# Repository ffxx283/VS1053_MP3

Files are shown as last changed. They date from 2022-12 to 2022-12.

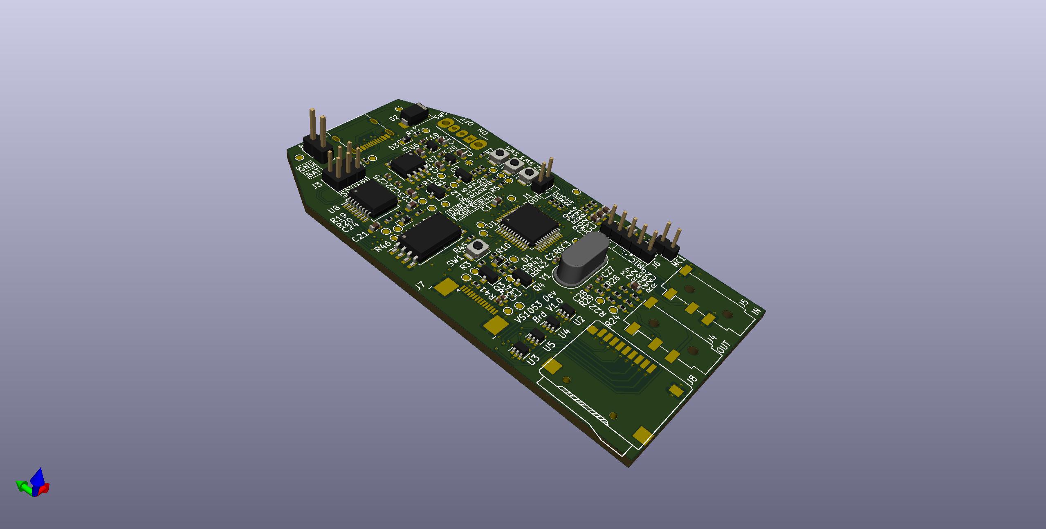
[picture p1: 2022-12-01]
Hardware_Project/效果图/正面.jpg

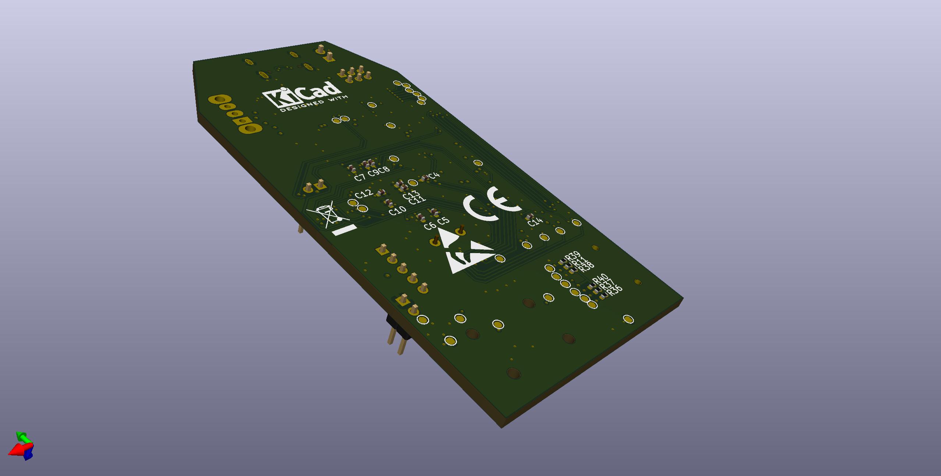
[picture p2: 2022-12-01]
Hardware_Project/效果图/反面.jpg

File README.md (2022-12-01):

# VS1053_MP3
基于VS1053芯片设计的MP3播放器

产品定位为一款可以对VS1053进行全面开发的开发板，产品的功能应当全面覆盖芯片的所有外设资源，但应该以将VS1053作为主控为重点，适当开发从机功能（SPI控制）。
TYPE-C接口，插入电脑直接对开发板进行下载调试（板载下载器），将读写SD卡的功能也加入此接口中（读卡器功能），可以使用跳线帽进行选择USB的通路。
带有液晶显示屏或者是OLED显示屏，带有按键，方便进行交互。

TYPE-C接口，插入电脑直接对开发板进行下载调试（板载下载器），将读写SD卡的功能也加入此接口中（读卡器功能），可以使用跳线帽进行选择USB的通路。

带有液晶显示屏或者是OLED显示屏，带有按键，方便进行交互。

主控：VS1053
USB转串口芯片：CH340N
SPI存储器芯片：AT93C66
电源芯片：RT9193-33GB、RT9193-18GB
SD卡控制器芯片：GL823
模拟单刀双掷开关SGM3157YC6/TR
显示屏选型：鸿欣达----YT144S025不带触摸
存储设备：TF卡
音频输入输出：3.5mm耳机孔输出+板载MIC

……
不测试了，下载调试软件的时候，软件直接就崩溃了，多次测试均未见效果，当成一个读卡器来用吧
VS1053芯片的生态不行，目前市面上大部分都是把它当做一个从机芯片来用，用作主机的案例太少，
官方对于此方面不够重视，软件也存在各种各样的问题，折腾不下去了。

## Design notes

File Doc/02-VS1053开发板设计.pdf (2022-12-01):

# VS1053开发板设计文档

冯星

1、设计需求

1.1、功能要求

1.2、芯片选型

2、电路设计

2.1、电源设计

2.1.1、供电

2.2、Type-C接口设计

2.2.1、串口下载和读写TF卡

2.2.2、VS1053和GL823对TF卡读取冲突

2.3、VS1053芯片电路设计

2.3.1、芯片电源、时钟、复位

2.3.2、芯片配置

2.3.3、程序存储

2.4、TF卡电路设计

2.5、音频电路设计

2.6、其他电路设计

2.6.1、显示屏接口

2.6.2、按键、LED电路

2.6.3、状态指示电路

### 1、设计需求

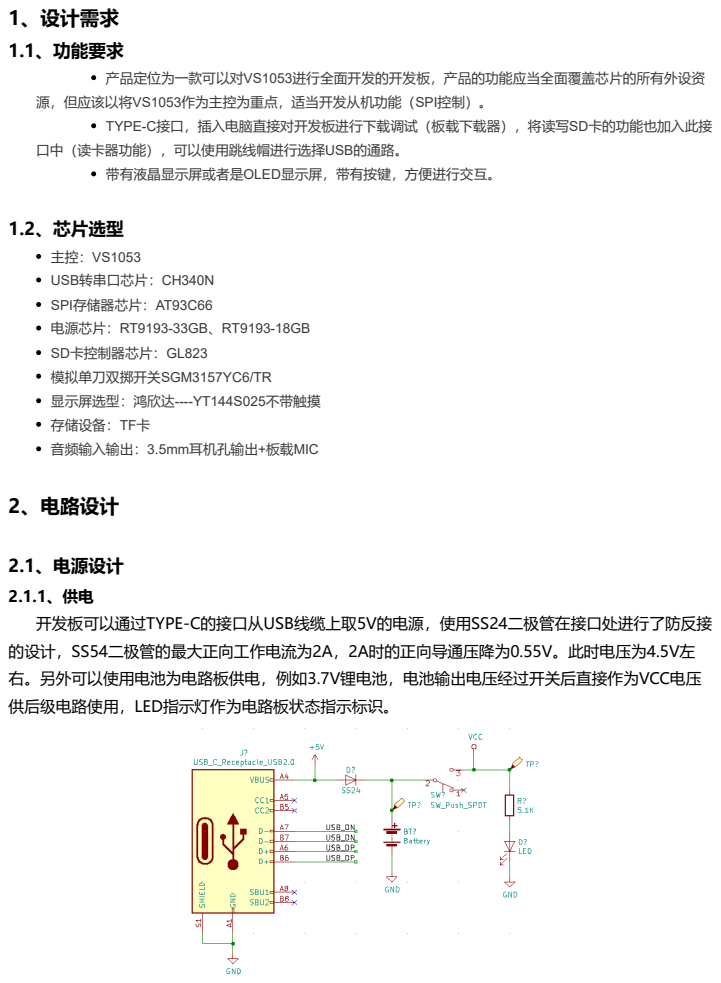
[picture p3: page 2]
1.1、功能要求; 产品定位为一款可以对VS1053进行全面开发的开发板，产品的功能应当全面覆盖芯片的所有外设资 源，但应该以将VS1053作为主控为重点，适当开发从机功能（SPI控制）。; 1.2、芯片选型; USB转串口芯片：CH340N; SPI存储器芯片：AT93C66; 电源芯片：RT9193-33GB、RT9193-18GB; SD卡控制器芯片：GL823; 模拟单刀双掷开关SGM3157YC6/TR 显示屏选型：鸿欣达----YT144S025不带触摸 存储设备：TF卡 音频输入输出：3.5mm耳机孔输出+板载MIC; 2、电路设计; 2.1、电源设计; 2.1.1、供电 开发板可以通过TYPE-C的接口从USB线缆上取5V的电源，使用SS24二极管在接口处进行了防反接 的设计，SS54二极管的最大正向工作电流为2A，2A时的正向导通压降为0.55V。此时电压为4.5V左 右。另外可以使用电池为电路板供电，例如3.7V锂电池，电池输出电压经过开关后直接作为VCC电压 供后级电路使用，LED指示灯作为电路板状态指示标识。

TYPE-C接口，插入电脑直接对开发板进行下载调试（板载下载器），将读写SD卡的功能也加入此接

口中（读卡器功能），可以使用跳线帽进行选择USB的通路。

带有液晶显示屏或者是OLED显示屏，带有按键，方便进行交互。

电路板的一级电源使用RT9193系列LDO电源芯片获得3.3V和1.8V的电压，芯片的输入电压范围为 2.5V~5.5V,最大输入电压不得超过6V，输出电压的精度为±2%，典型输出电流为400mA，关断电流 为0.01uA。使用3.3V型号1.8V的芯片型号为VS1053和其他外设供电，输入输出电容均采用手册推荐 的值。

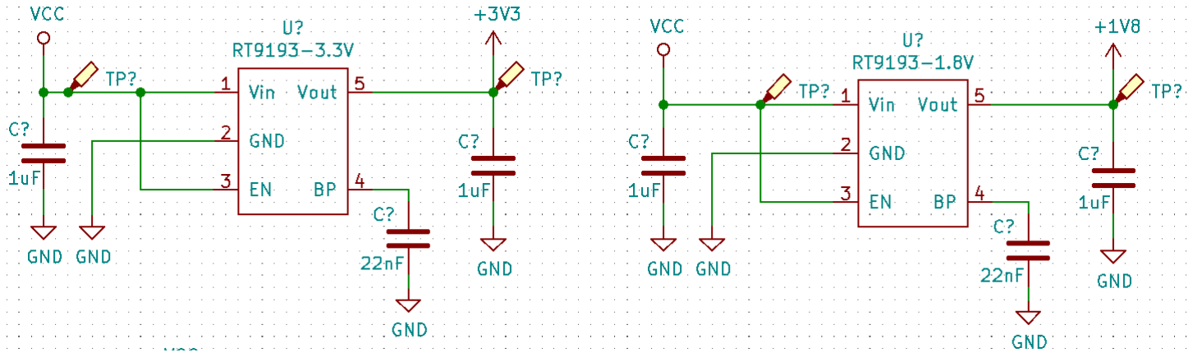
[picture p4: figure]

2.2、Type-C接口设计
2.2.1、串口下载和读写TF卡
USB线插入后给设备供电，系统开始工作，Type-C接口支持正反插。

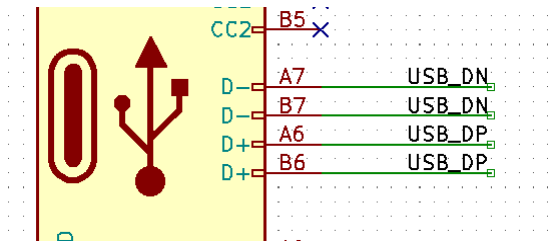
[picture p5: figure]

串口下载程序的功能和读写TF卡的功能可以使用跳冒手动设置，设置USB_DP和DN连接到不同的 USB网络上即可。

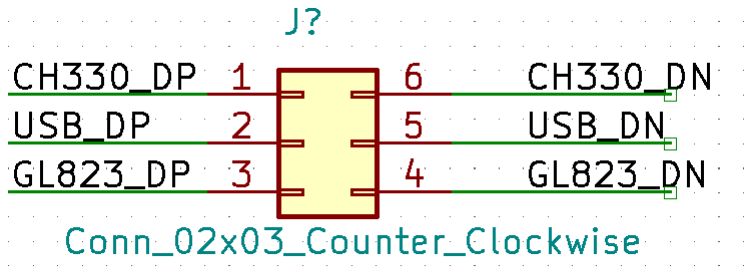
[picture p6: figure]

串口下载程序大部分使用于调试开发阶段，用于给VS1053芯片烧录程序，使用CH330N型号的 USB转串口芯片，此芯片不需要设置外部晶振即可工作。

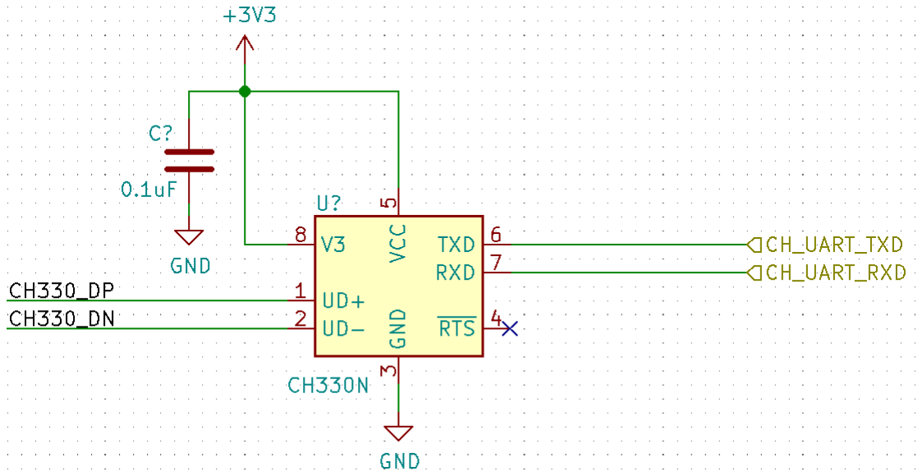
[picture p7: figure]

读写TF卡功能用于从电脑上往TF卡中存储数据，这样就不需要将TF取出，插入读卡器中再进行歌 曲的更新了，直接使用Type-C接口即可进行读写，大大简化了操作步骤。 芯片的供电电压为5V，只有在USB设备插入的时候才会有5V的电压，而且必须软件控制设备打卡 5V的电源控制开关，这样才可成功得给GL823K芯片供电。

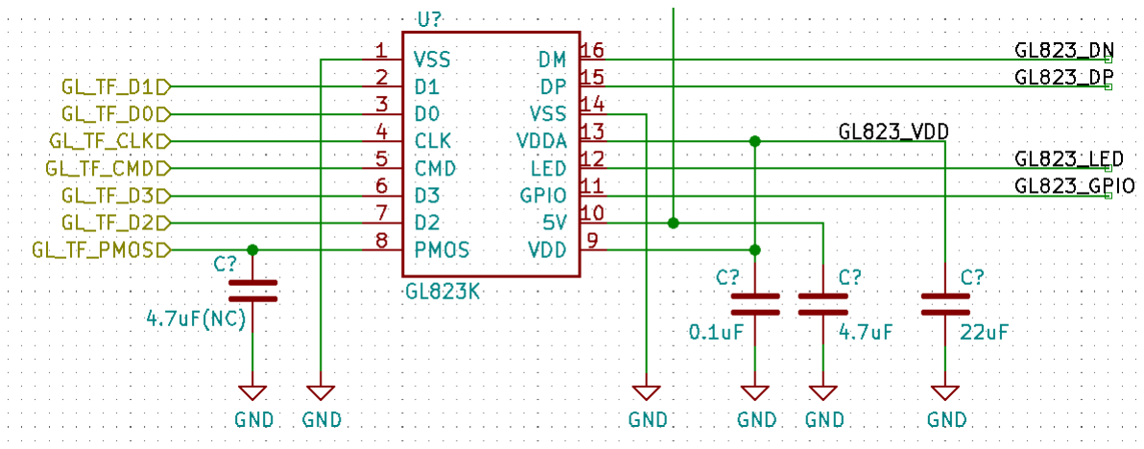
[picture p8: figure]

2.2.2、VS1053和GL823对TF卡读取冲突 GL823芯片和VS1053都需要对TF卡进行读写，如何设置GL823与VS1053两个芯片自动切换对TF 卡的使用权。
官方的开发板的解决方案是：检测是否有USB设备插入，来设置三态门芯片，间接控制TF卡被不同 的主控芯片所控制。但是官方的板子带有电池，在不插入TF卡的时候是可以使用电池供电来使得 VS1053控制TF卡的，插入USB后，VS1053不播放音乐，从而设置三态门的开关，使得TF读卡芯片 （CBM4082）对TF卡进行读写。而且官方板上的CBM4082读卡器芯片是带有使能端的，USB的供电 电源提供这个使能信号。
本开发板使用的方案：使用模拟单刀双掷开关SGM3157YC6/TR来进行TF卡信号的切换，将芯片 的公共端连接在TF卡的控制信号上，将常闭端连接到VS1053的TF卡控制信号线上，常开端连接在 GL823的TF卡控制信号线上；

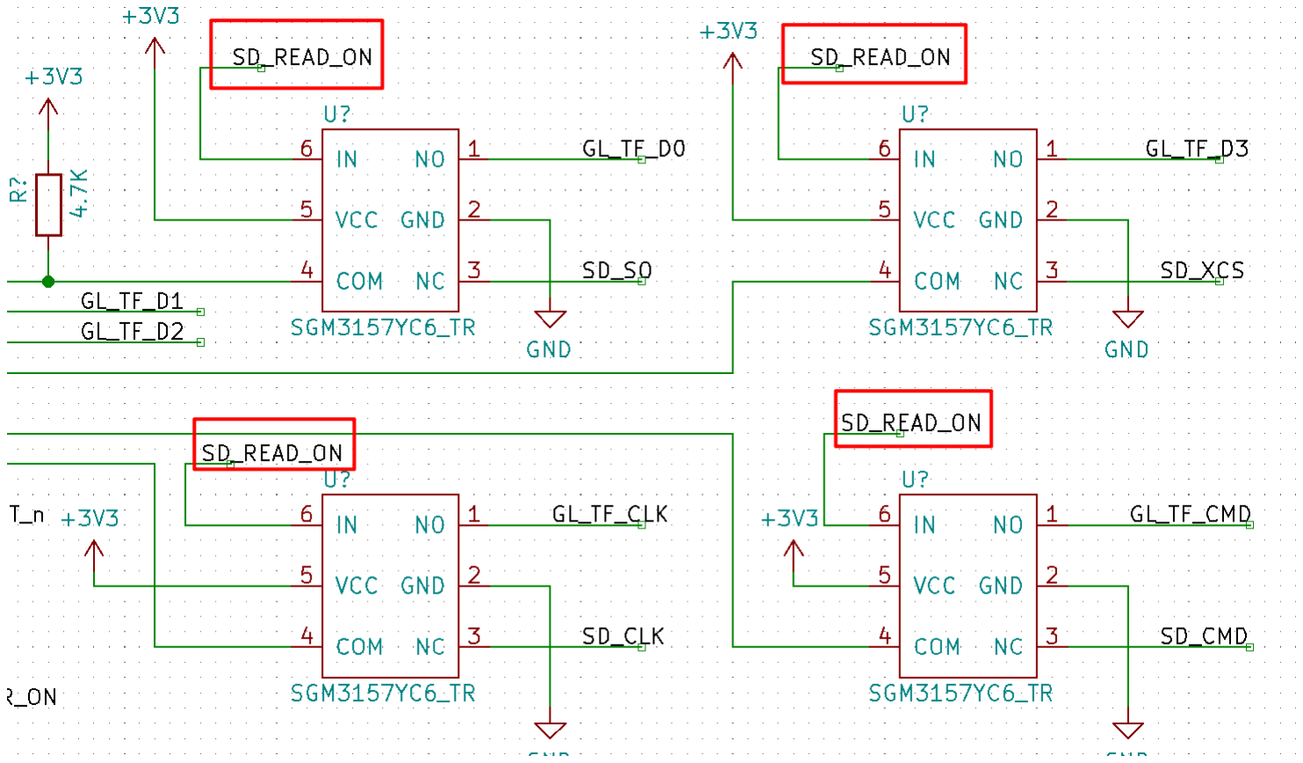
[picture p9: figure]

模拟开关的控制信号连接到VS1053的一个IO（默认为低电平），系统上电（USB供电或者电池供 电）默认状态下开发板上的VS1053读取TF卡播放音频，当需要对TF卡进行读写操作时，VS1053控制 IO口输出高电平，GL823芯片通电，然后读写TF卡。

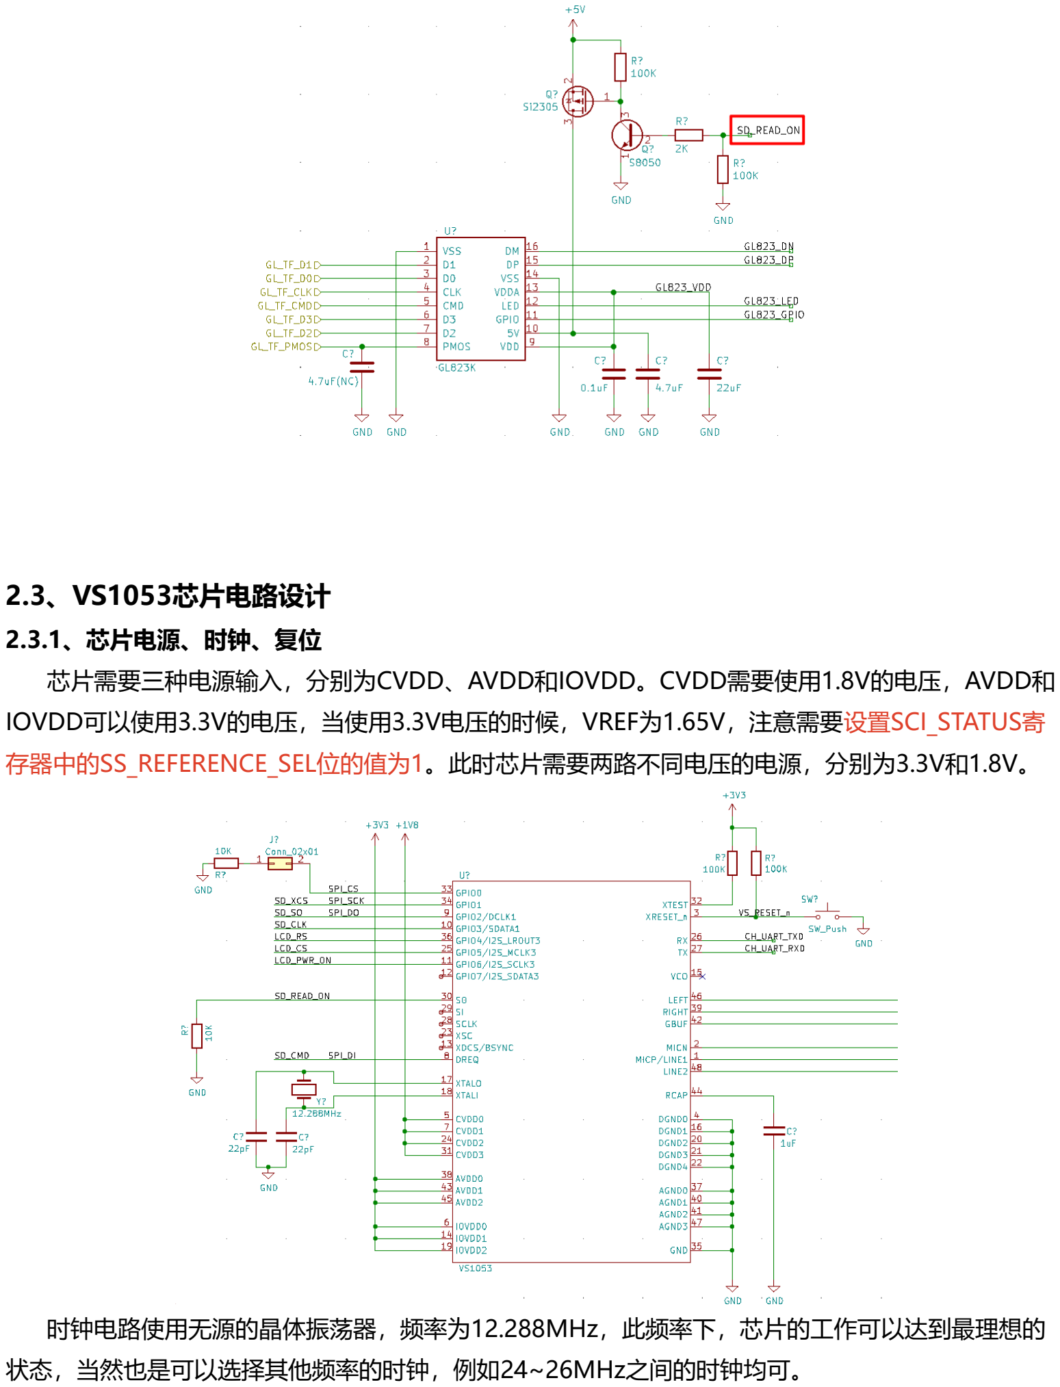
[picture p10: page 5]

2.3、VS1053芯片电路设计
2.3.1、芯片电源、时钟、复位
芯片需要三种电源输入，分别为CVDD、AVDD和IOVDD。CVDD需要使用1.8V的电压，AVDD和 IOVDD可以使用3.3V的电压，当使用3.3V电压的时候，VREF为1.65V，注意需要设置SCI_STATUS寄 存器中的SS_REFERENCE_SEL位的值为1。此时芯片需要两路不同电压的电源，分别为3.3V和1.8V。

时钟电路使用无源的晶体振荡器，频率为12.288MHz，此频率下，芯片的工作可以达到最理想的 状态，当然也是可以选择其他频率的时钟，例如24~26MHz之间的时钟均可。

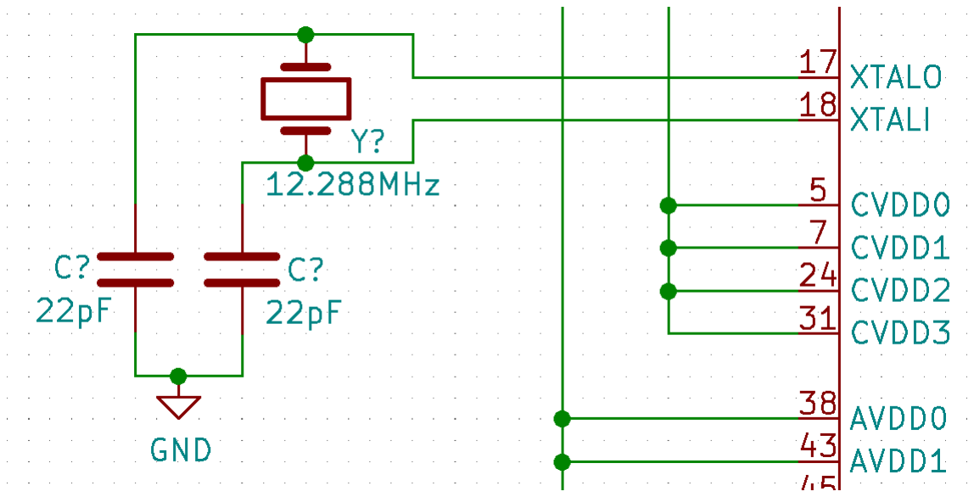
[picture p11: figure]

复位电路，低电平有效。外部上拉至3.3V，需要复位的时候，使用外部按键将其下拉到GND，IO 处于低电平，完成复位操作。

2.3.2、芯片配置

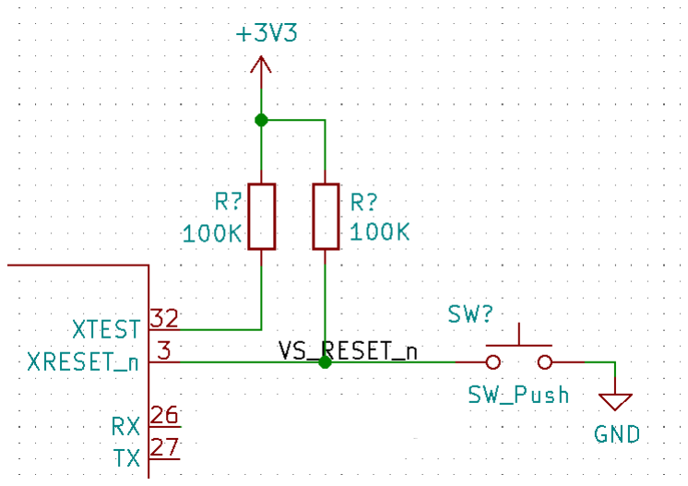
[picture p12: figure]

XTEST引脚为芯片保留引脚，根据芯片手册要求，上拉到IOVDD电源上，即3.3V电源。

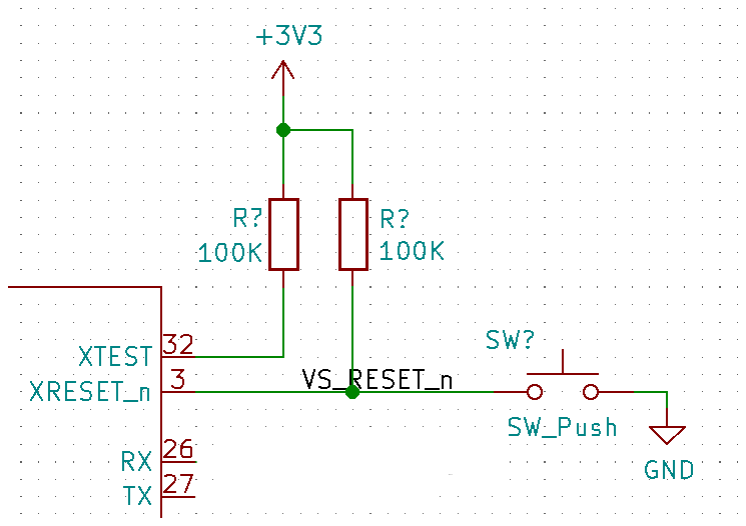
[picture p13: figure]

RCAP引脚使用一个1uF的电容连接到GND网络。

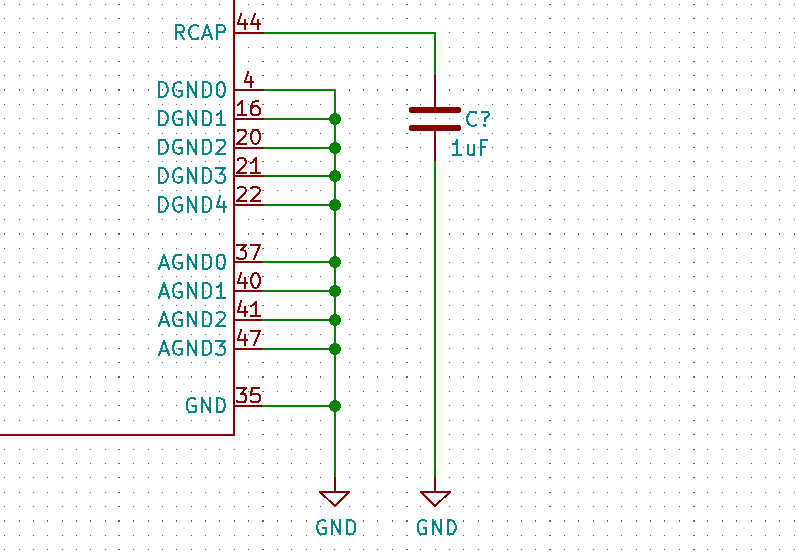
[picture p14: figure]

当芯片启动时，GPIO0引脚为高电平，则芯片就有进入SPI BOOT模式，即从SPI存储器件中读取程 序代码来运行，如下图使用100KOhm的电阻上拉引脚到3.3V，同时准备了一个跳线帽用来设置其接 地。

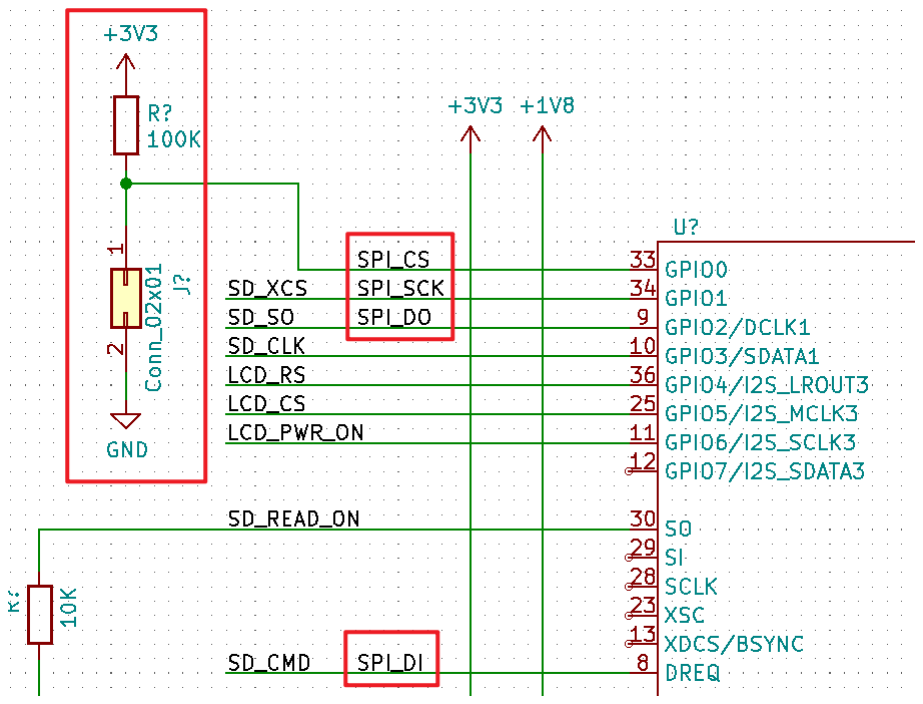
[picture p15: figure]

当进入SPI BOOT模式的时候，芯片的几个多功能引脚功能会发生相应的变化，如下表所示的为此 时芯片引脚的功能。

2.3.3、程序存储

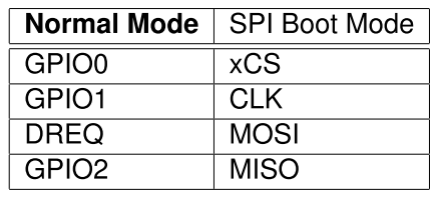
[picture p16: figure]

VS1053芯片的数据手册要求“The memory has to be an SPI Bus Serial EEPROM with 16-bit or 24-bit addresses. ”。由于SPI接口的FLASH芯片较多，但是SPI接口的EEPROM不常见，所以使 用两个芯片进行设计，最终选择哪个需要设计验证。
AT93C66芯片是Atmel公司的4Kbits的三线串行EEPROM存储器，由于要求16bits的Address， AT93C66手册的要求“When the ORG pin is connected to VCC, the x 16 organization is selected. When it is connected to ground, the x 8 organization is selected.”，设置ORG的引脚 可以连接到VCC电压上，也可以连接到GND上，默认设置到GND上，使用8bits数据位宽。 W25Q32是Winbond的32Mbits SPI FLASH芯片，具有24bits的地址线位宽，虽然VS1053手册 中写到的是SPI EEPROM，但是官方开发板上使用的就是W25X16或者GD25Q16系列的FLASH芯片， 使用此芯片做测试。

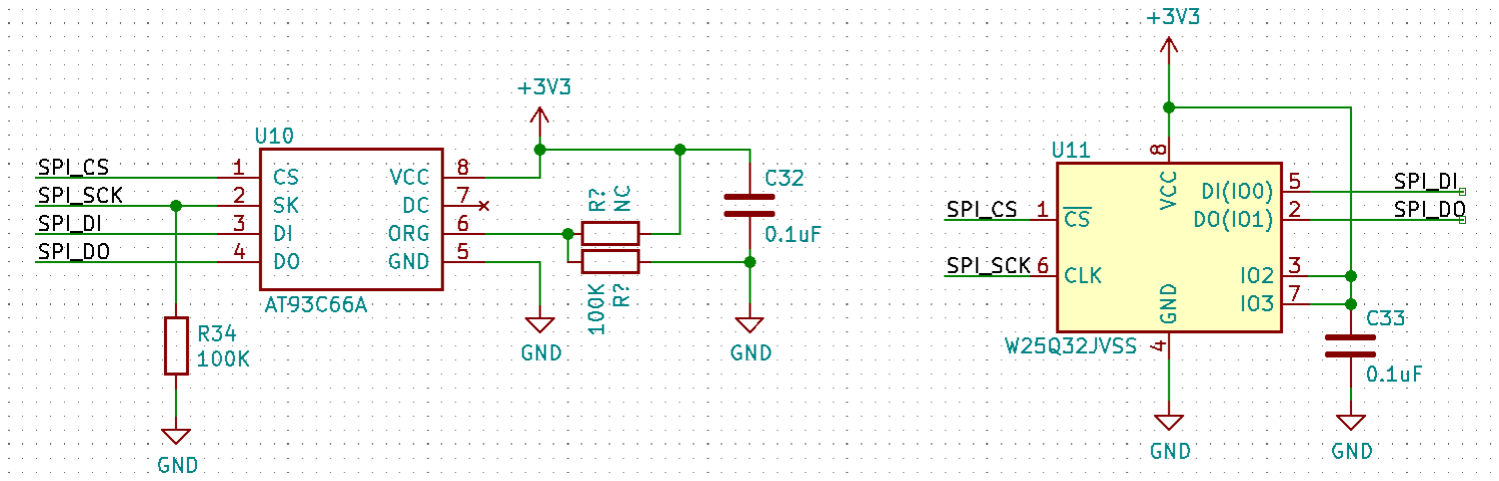
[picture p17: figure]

2.4、TF卡电路设计

参考官方的开发板设计TF卡电路如下图，VS1053是使用的SPI或者单线SDIO来读取的TF卡中数 据，而读卡器芯片GL823是使用的四线的SDIO来读取TF卡中的内容。

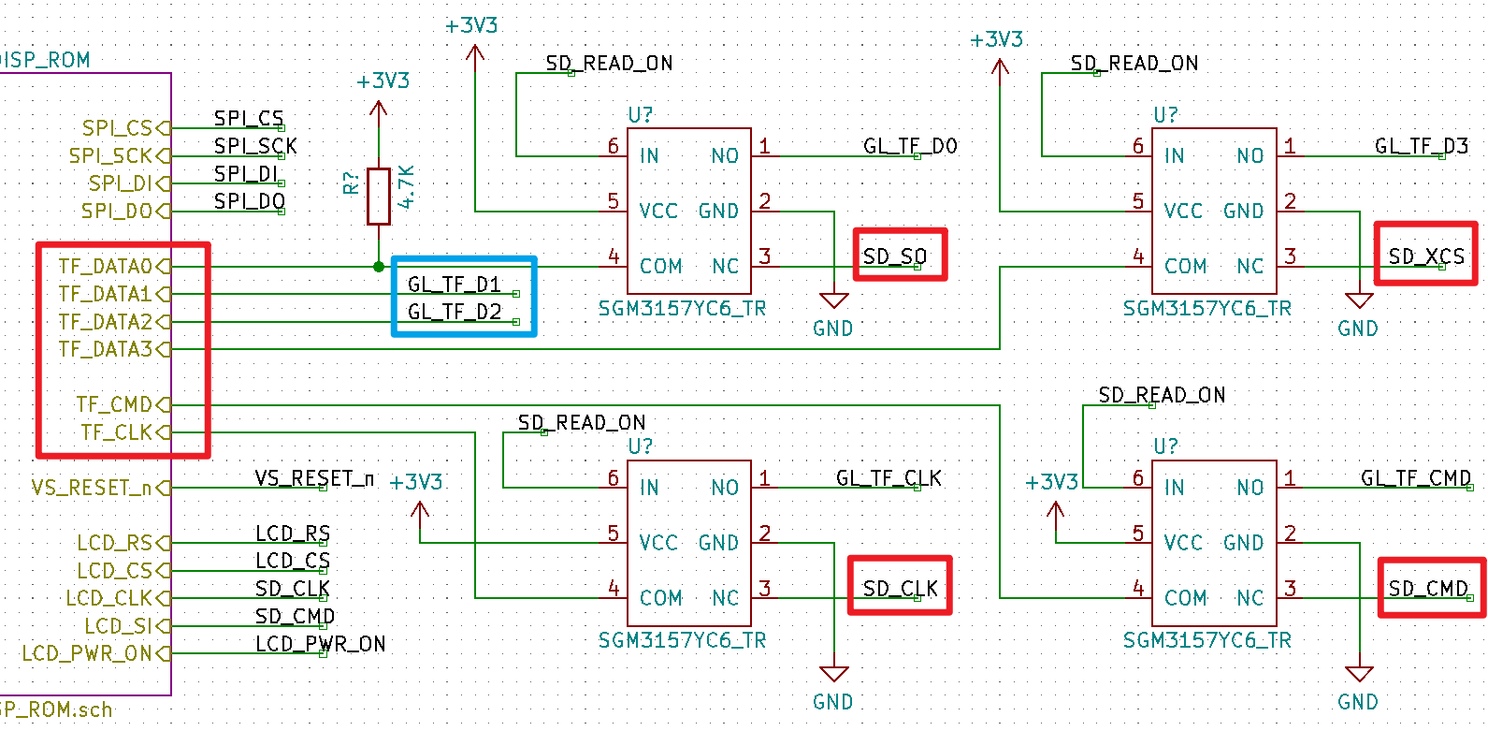
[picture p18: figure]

2.5、音频电路设计
参考官方电路设计：

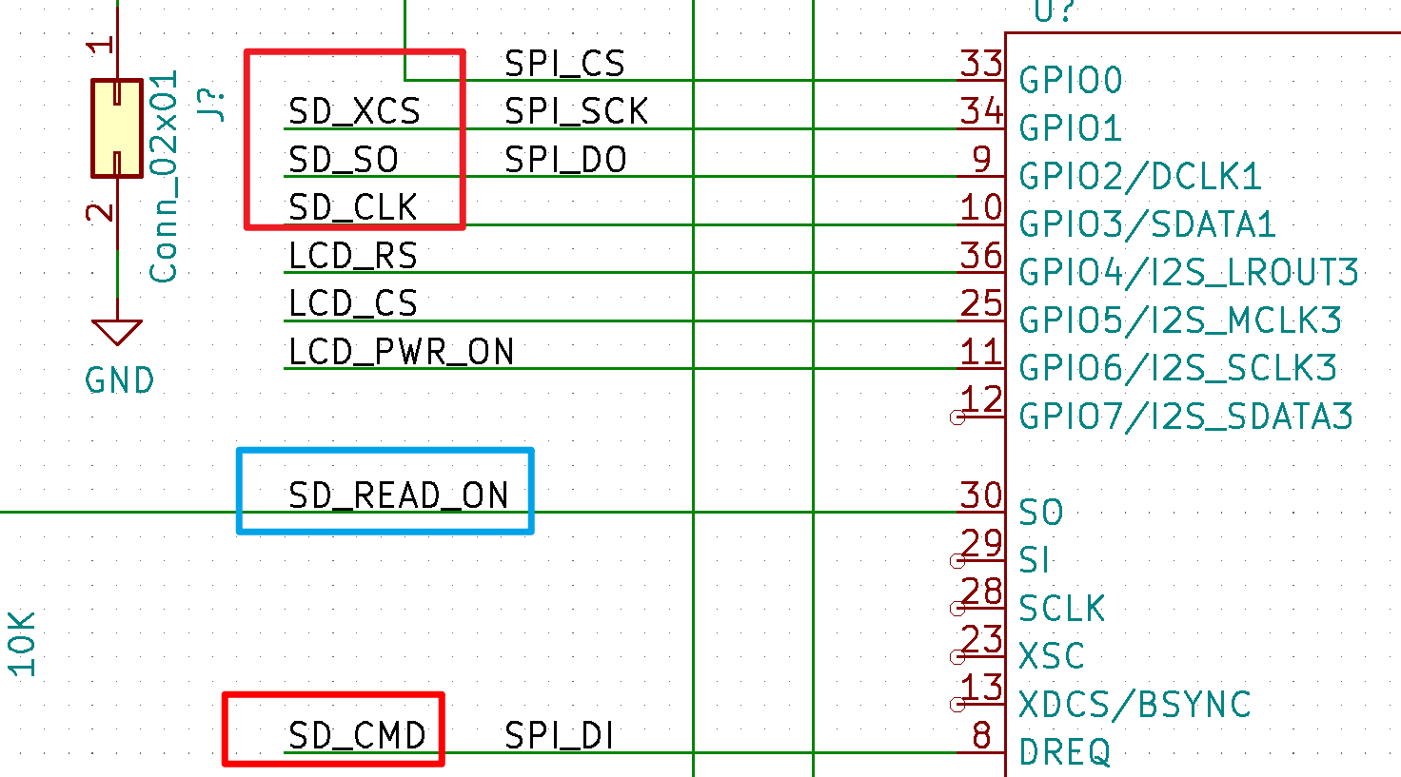
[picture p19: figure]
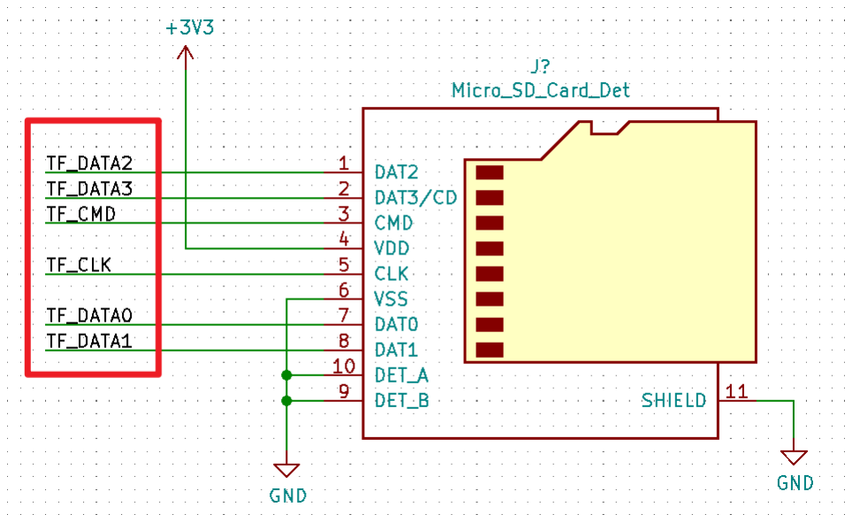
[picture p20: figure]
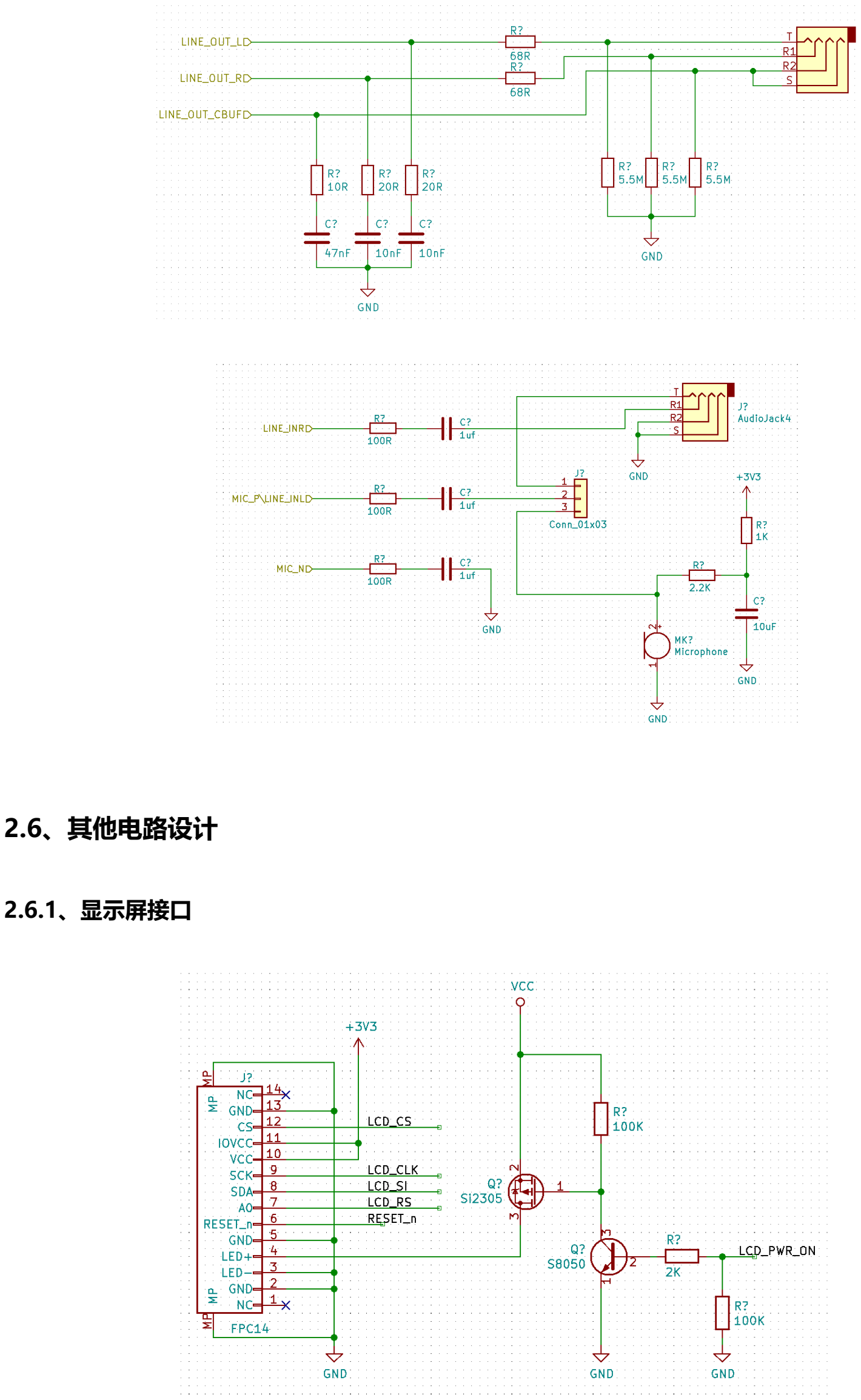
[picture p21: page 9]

2.6、其他电路设计

2.6.1、显示屏接口

2.6.2、按键、LED电路
参考官方开发板的按键IO分配策略，

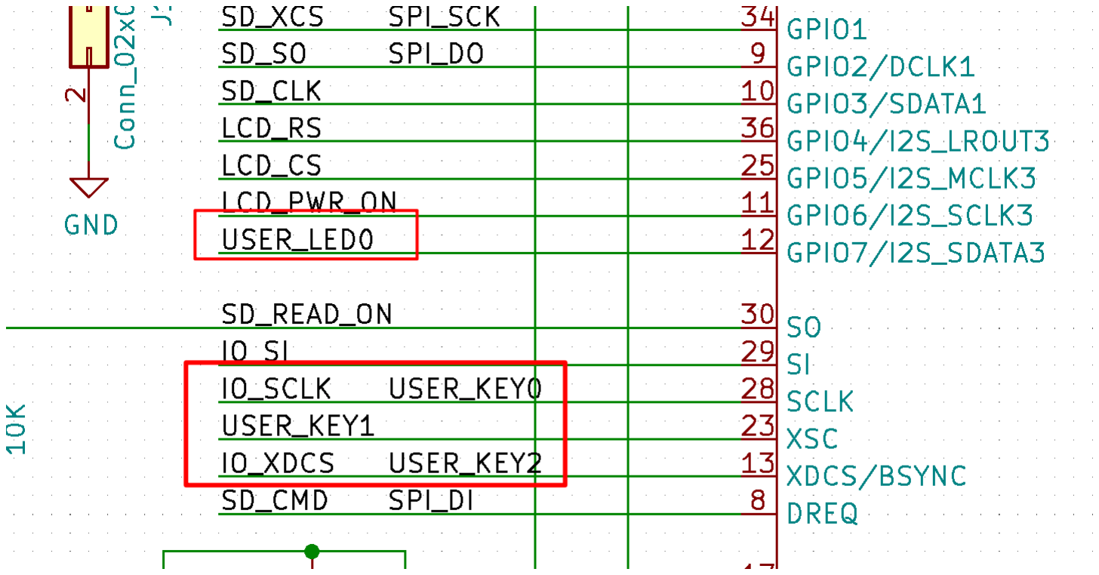
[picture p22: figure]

2.6.3、状态指示电路

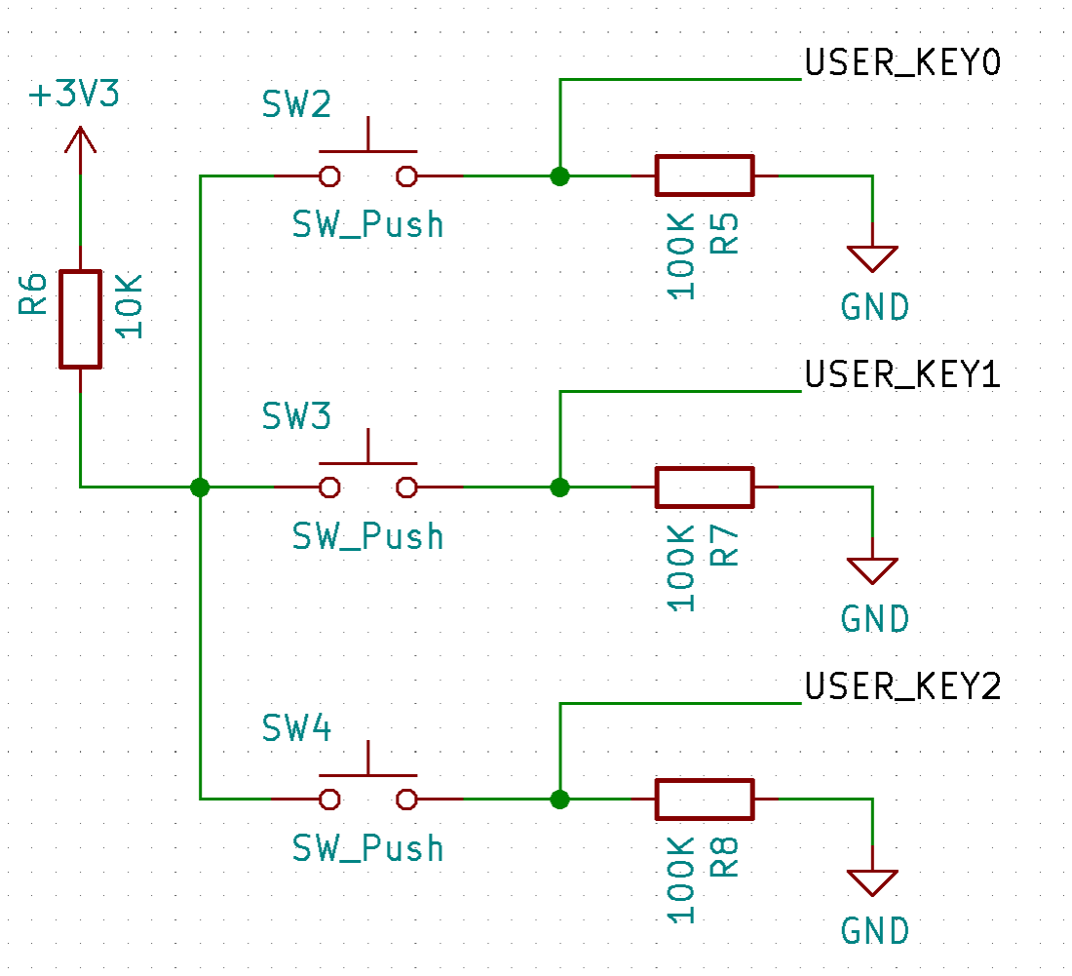
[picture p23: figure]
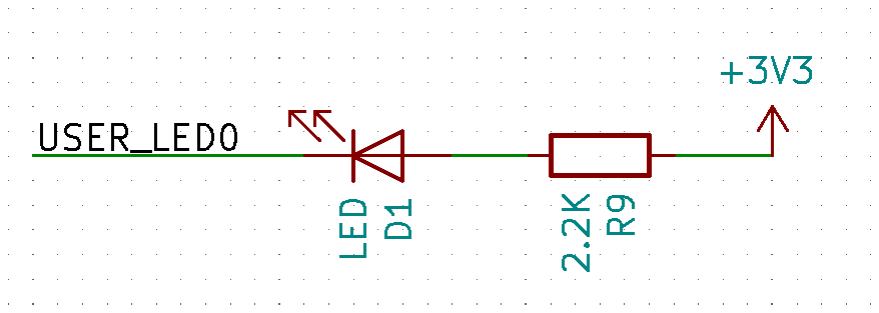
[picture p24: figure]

使用一颗LED灯来指示GL823的工作状态。

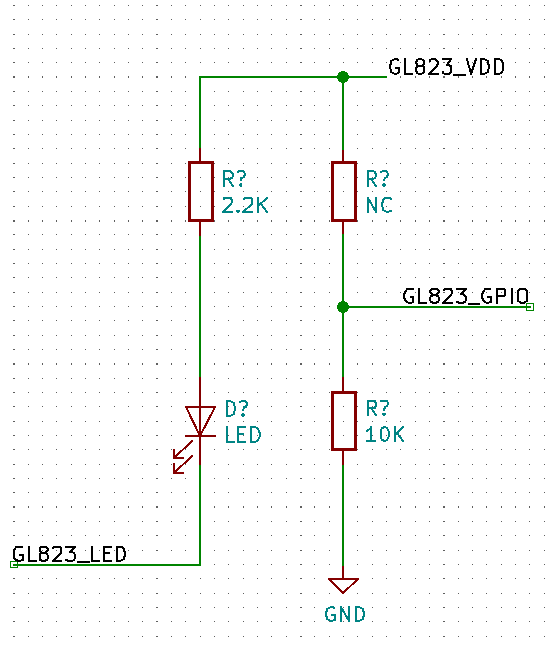
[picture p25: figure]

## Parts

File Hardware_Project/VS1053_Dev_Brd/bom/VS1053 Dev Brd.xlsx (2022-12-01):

Item | Qty | Reference(s) | Value | Footprint | 采购情况 | 总价(元)
1 | 1 | BT1 | Battery | Connector_PinHeader_2.54mm:PinHeader_1x02_P2.54mm_Vertical | /
2 | 8 | C1, C15, C16, C17, C18, C29, C30, C32 | 1uF | Capacitor_SMD:C_0603_1608Metric | 50 | 2
3 | 2 | C2, C3 | 22pF | Capacitor_SMD:C_0402_1005Metric | 100 | 1.5
 | 17 | C4, C5, C6, C7, C8, C9, C10, C11, C12, C13, C14, C22, C25, C33, C34, C35, C36 | 0.1uF | Capacitor_SMD:C_0402_1005Metric | 100 | 1.5
 | 2 | C19, C20 | 22nF | Capacitor_SMD:C_0402_1005Metric | 100 | 1.5
 | 1 | C21 | 4.7uF(NC) | Capacitor_SMD:C_0603_1608Metric | /
 | 1 | C23 | 4.7uF | Capacitor_SMD:C_0603_1608Metric | 50 | 2.5
 | 2 | C24, C31 | 10uF | Capacitor_SMD:C_0603_1608Metric | 50 | 3
 | 1 | C26 | 47nF | Capacitor_SMD:C_0603_1608Metric | 50 | 2
 | 2 | C27, C28 | 10nF | Capacitor_SMD:C_0402_1005Metric | 100 | 1.5
 | 3 | D1, D3, D4 | LED | Diode_SMD:D_0603_1608Metric | 100 | 1
 | 1 | D2 | SS24 | Diode_SMD:D_SMA | 10 | 0.3
 | 1 | J1 | Conn_02x01 | Connector_PinHeader_2.00mm:PinHeader_1x02_P2.00mm_Vertical | 1 | 0.14
 | 1 | J2 | USB_C_Receptacle_USB2.0 | Connector_USB:USB_C_Receptacle_Palconn_UTC16-G | /
 | 1 | J3 | Conn_02x03_Counter_Clockwise | Connector_PinHeader_2.00mm:PinHeader_2x03_P2.00mm_Vertical | 1 | 0.28
 | 2 | J4, J5 | AudioJack4 | Connector_Audio:Jack_3.5mm_PJ320D_Horizontal | 3 | 0.36
 | 1 | J6 | Conn_01x05 | Connector_PinHeader_2.00mm:PinHeader_1x05_P2.00mm_Vertical | /
 | 1 | J7 | FPC14 | Connector_FFC-FPC:TE_1-1734839-4_1x14-1MP_P0.5mm_Horizontal | 1 | 8 | TFT显示屏
 | 1 | J8 | Micro_SD_Card_Det | Connector_Card:SD-MINI-X | 2 | 0.32
 | 1 | MC1 | Microphone | Connector_PinHeader_2.00mm:PinHeader_1x02_P2.00mm_Vertical | 1 | 0.3
 | 2 | Q1, Q3 | Si2305 | Package_TO_SOT_SMD:SOT-23 | 3 | 0.34
 | 2 | Q2, Q4 | S8050 | Package_TO_SOT_SMD:SOT-23 | 100 | 2
 | 11 | R1, R2, R3, R5, R8, R9, R12, R17, R35, R43, R46 | 100K | Resistor_SMD:R_0402_1005Metric | 100 | 1.8
 | 6 | R4, R7, R11, R13, R20, R45 | 10K | Resistor_SMD:R_0402_1005Metric | 100 | 1.8
 | 1 | R6 | NC(5.6M) | Resistor_SMD:R_0402_1005Metric | /
 | 5 | R10, R16, R18, R33, R42 | 2.2K | Resistor_SMD:R_0402_1005Metric | 100 | 1.8
 | 3 | R14, R15, R41 | NC(0R) | Resistor_SMD:R_0402_1005Metric | 100 | 1.8
 | 8 | R19, R21, R36, R37, R38, R39, R40, R44 | NC(10K) | Resistor_SMD:R_0402_1005Metric | /
 | 2 | R22, R23 | 68R/100R | Resistor_SMD:R_0402_1005Metric | /
 | 3 | R24, R25, R26 | 5.6M | Resistor_SMD:R_0402_1005Metric | 100 | 1.8
 | 3 | R27, R28, R29 | 20R | Resistor_SMD:R_0402_1005Metric | 100 | 1.8
 | 3 | R30, R31, R34 | 100R | Resistor_SMD:R_0402_1005Metric | 100 | 1.8
 | 1 | R32 | 1K | Resistor_SMD:R_0402_1005Metric | 100 | 1.8
 | 4 | SW1, SW2, SW3, SW4 | SW_Push | Button_Switch_SMD:SW_SPST_B3U-1000P | 10 | 0.9
 | 1 | SW5 | SW_Push_SPDT | Button_Switch_THT:SW_CuK_OS102011MA1QN1_SPDT_Angled | 20 | 1.5
 | 1 | U1 | VS1053 | Package_QFP:LQFP-48_7x7mm_P0.5mm | 1 | 16
 | 4 | U2, U3, U4, U5 | SGM3157YC6_TR | Package_TO_SOT_SMD:SOT-363_SC-70-6 | 5 | 1.2
 | 1 | U6 | RT9193-3.3V | Package_TO_SOT_SMD:SOT-353_SC-70-5 | 1 | 0.42 | RT9013
 | 1 | U7 | RT9193-1.8V | Package_TO_SOT_SMD:SOT-353_SC-70-5 | 1 | 0.24
 | 1 | U8 | GL823K | Package_SO:SSOP-16_5.3x6.2mm_P0.65mm | 1 | 2
 | 1 | U9 | CH330N | Package_SO:SOIC-8_3.9x4.9mm_P1.27mm | 1 | 1.78
 | 1 | U10 | AT93C66A | Package_SO:SOIC-8_5.275x5.275mm_P1.27mm | 1 | 0.59
 | 1 | U11 | W25Q32JVSS | Package_SO:SOIC-8_5.275x5.275mm_P1.27mm | /
 | 1 | Y1 | 12.288MHz | Crystal:Crystal_HC49-4H_Vertical | 1 | 0.19
 |  |  |  | 2mm跳线帽 | 100 | 3

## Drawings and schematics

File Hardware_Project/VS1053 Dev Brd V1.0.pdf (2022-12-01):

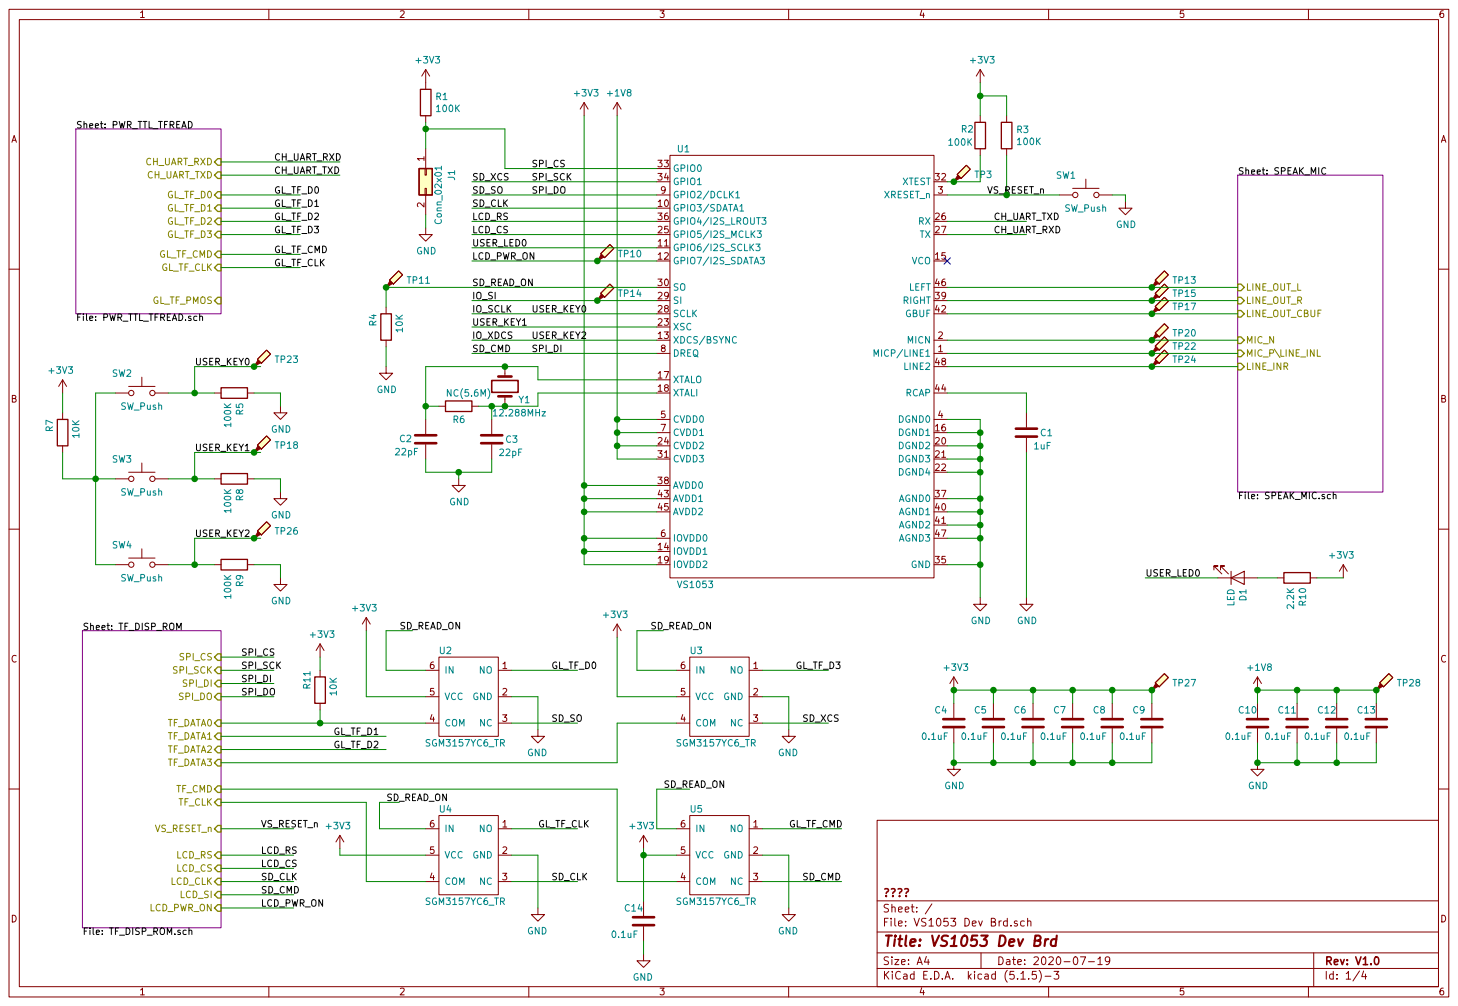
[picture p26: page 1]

File: VS1053 Dev Brd.sch Sheet: /
Id: 1/4 Title: VS1053 Dev Brd

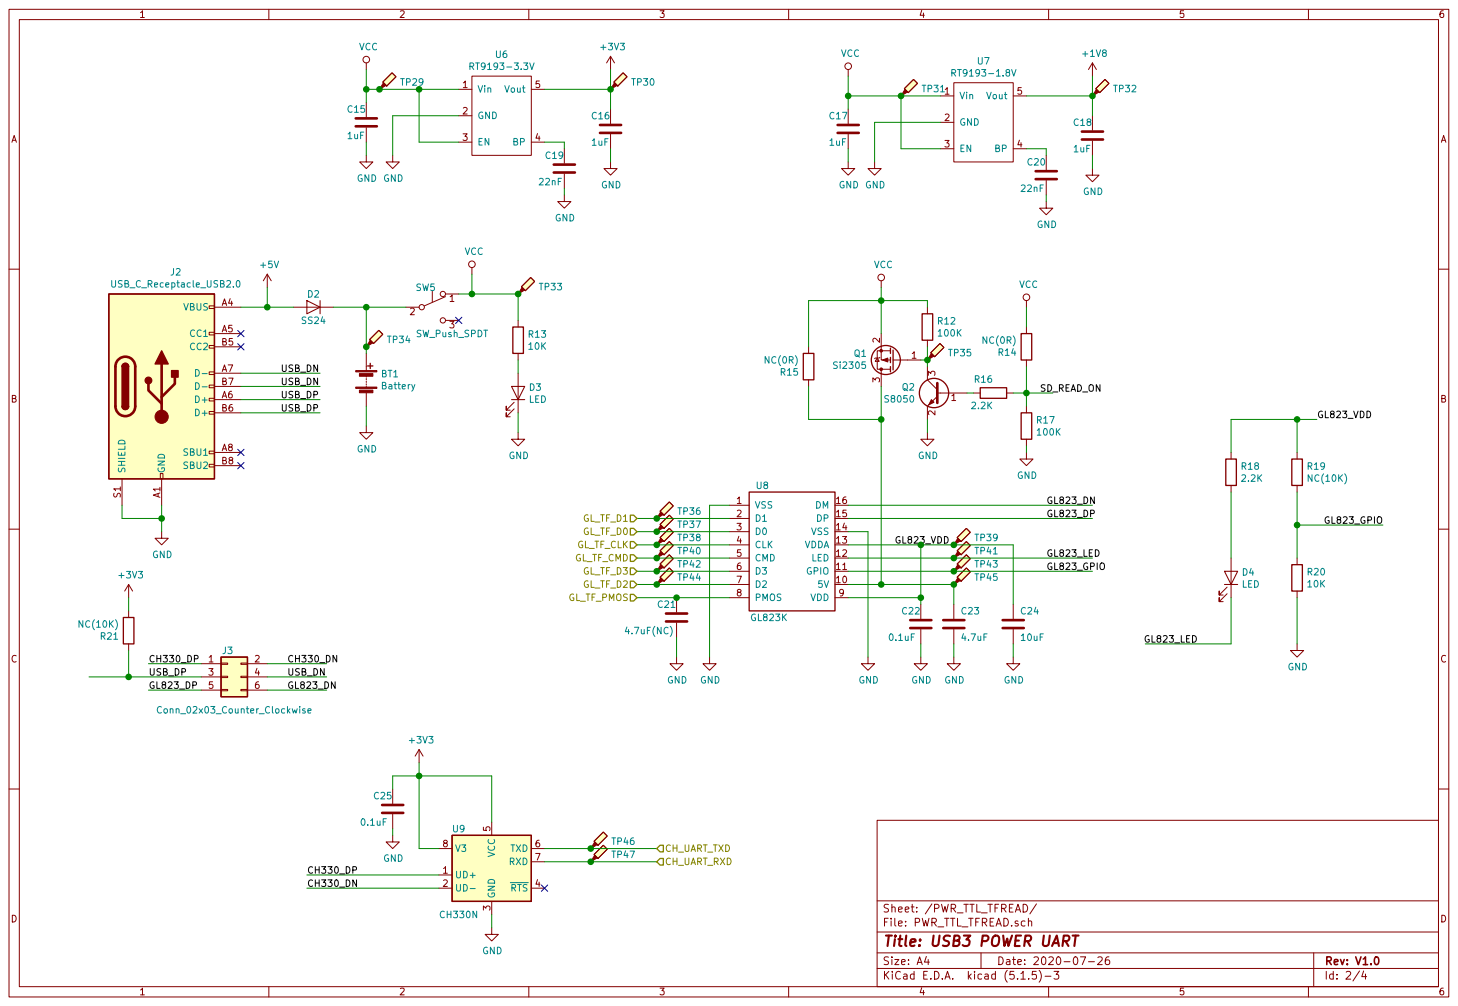
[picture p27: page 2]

Sheet: /PWR_TTL_TFREAD/
File: PWR_TTL_TFREAD.sch
Id: 2/4 Title: USB3 POWER UART

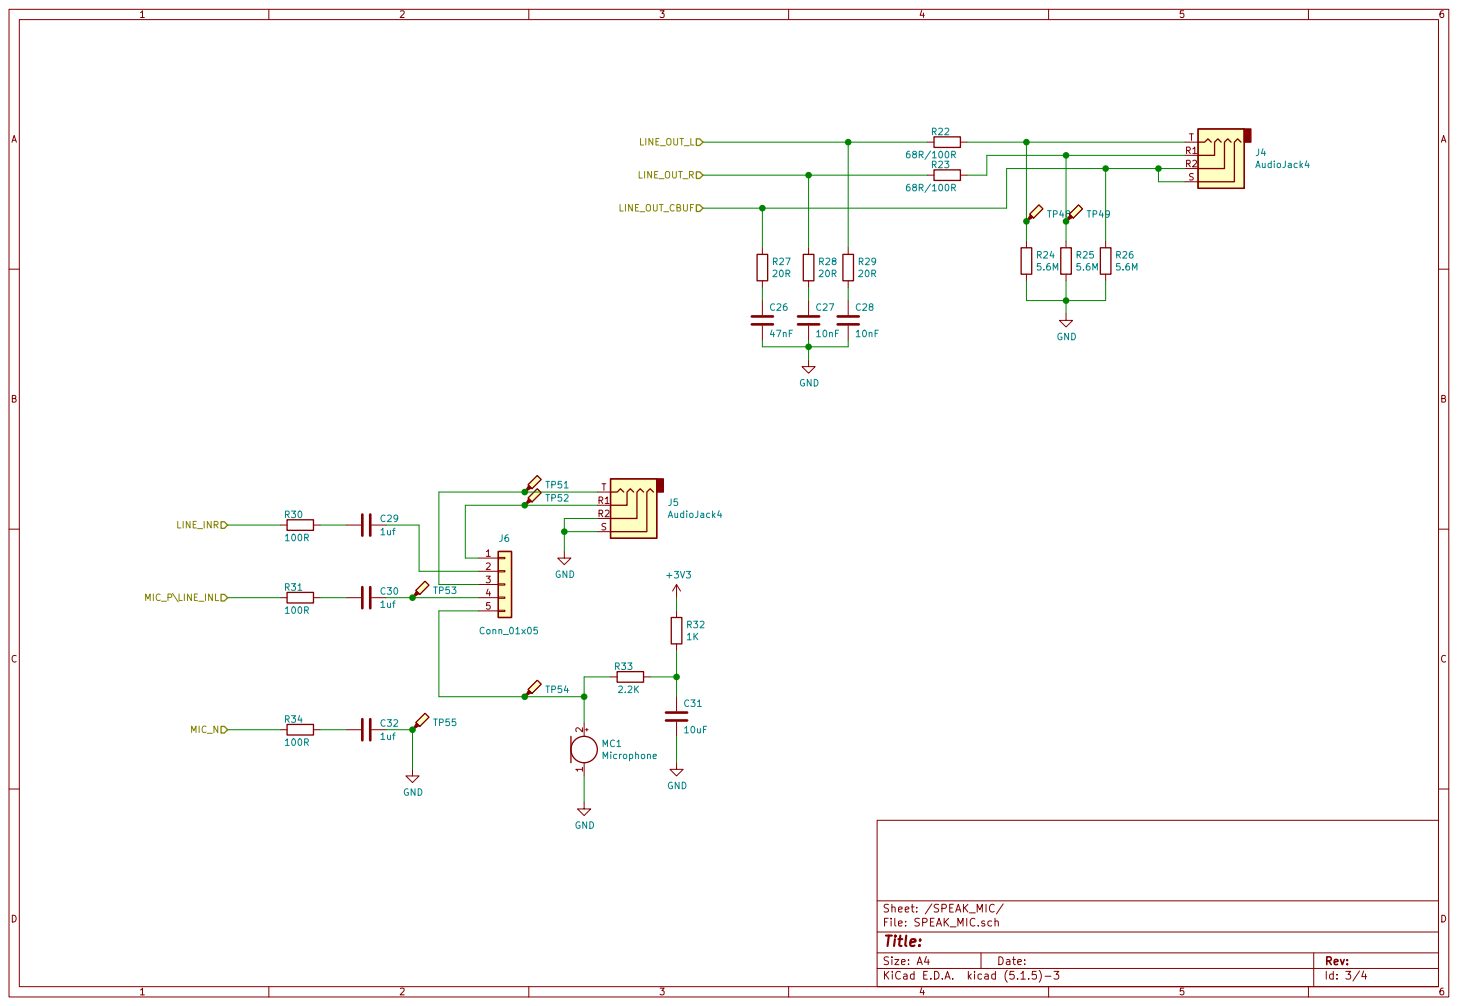
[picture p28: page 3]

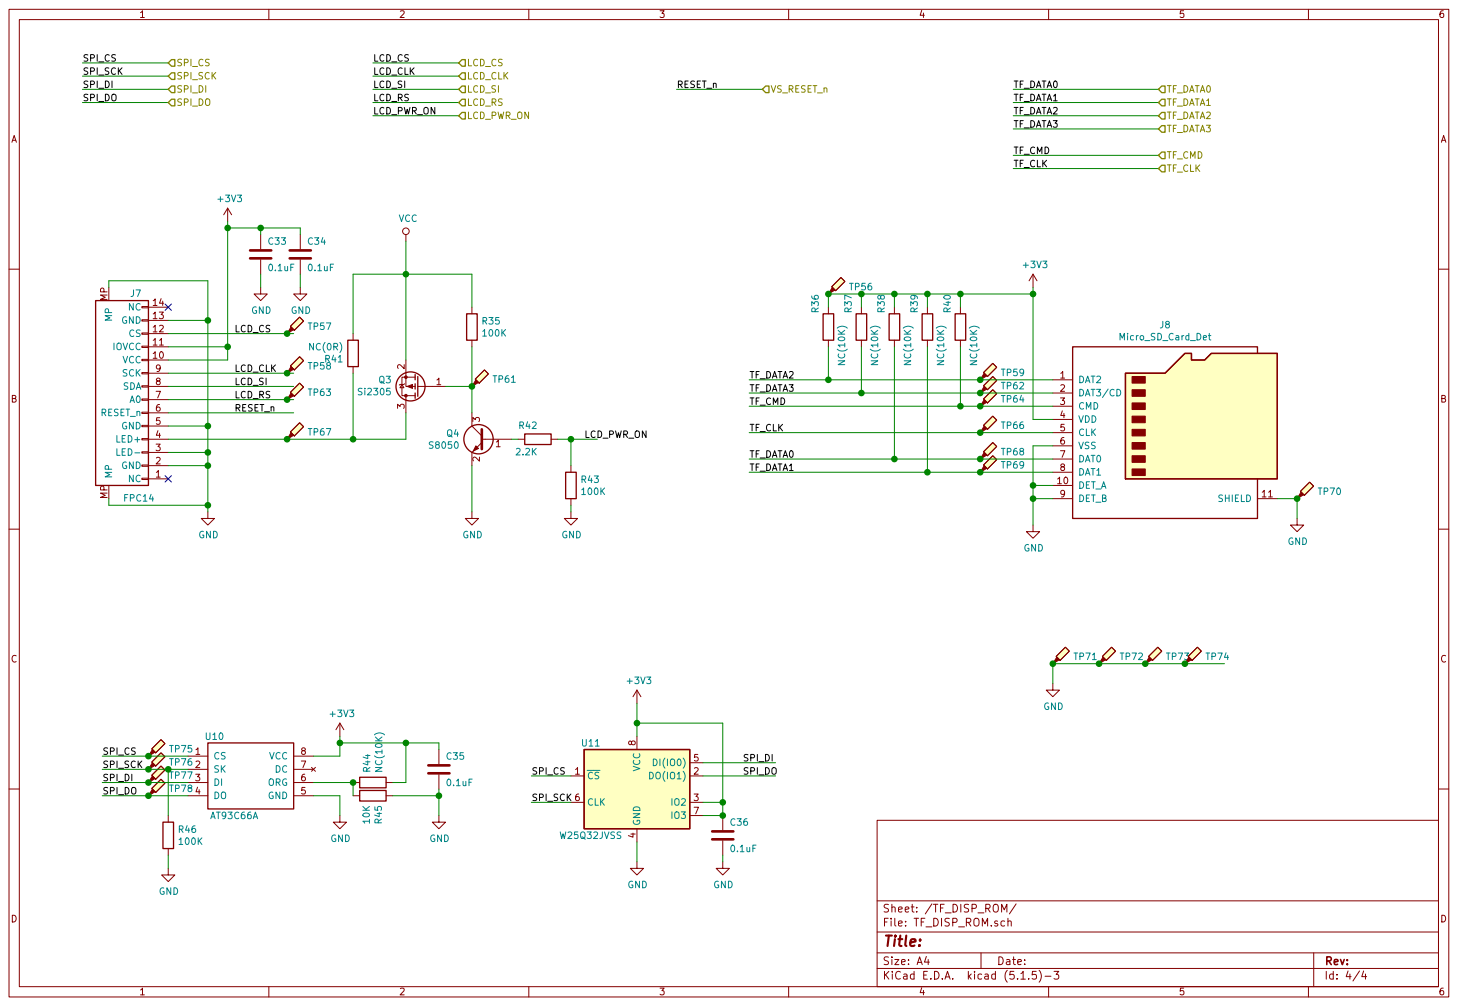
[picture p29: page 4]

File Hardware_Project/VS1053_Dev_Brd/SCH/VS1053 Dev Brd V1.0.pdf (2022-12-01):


File: VS1053 Dev Brd.sch Sheet: /
Id: 1/4 Title: VS1053 Dev Brd


Sheet: /PWR_TTL_TFREAD/
File: PWR_TTL_TFREAD.sch
Id: 2/4 Title: USB3 POWER UART



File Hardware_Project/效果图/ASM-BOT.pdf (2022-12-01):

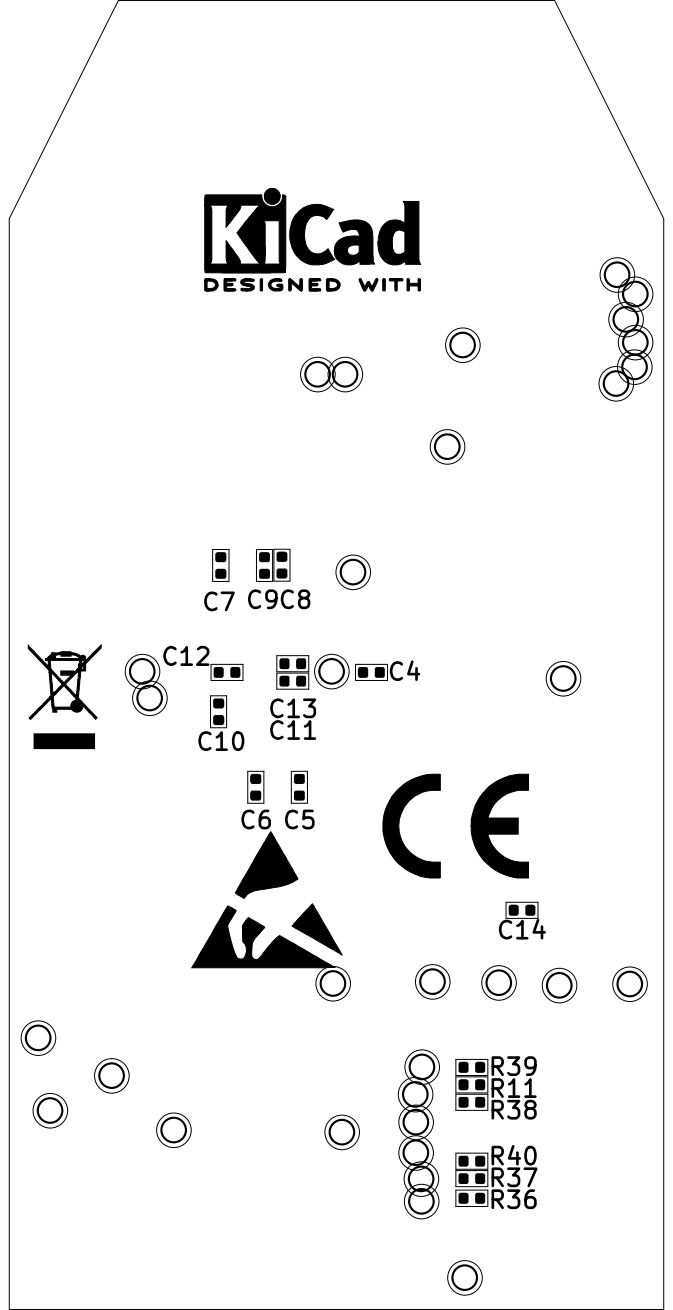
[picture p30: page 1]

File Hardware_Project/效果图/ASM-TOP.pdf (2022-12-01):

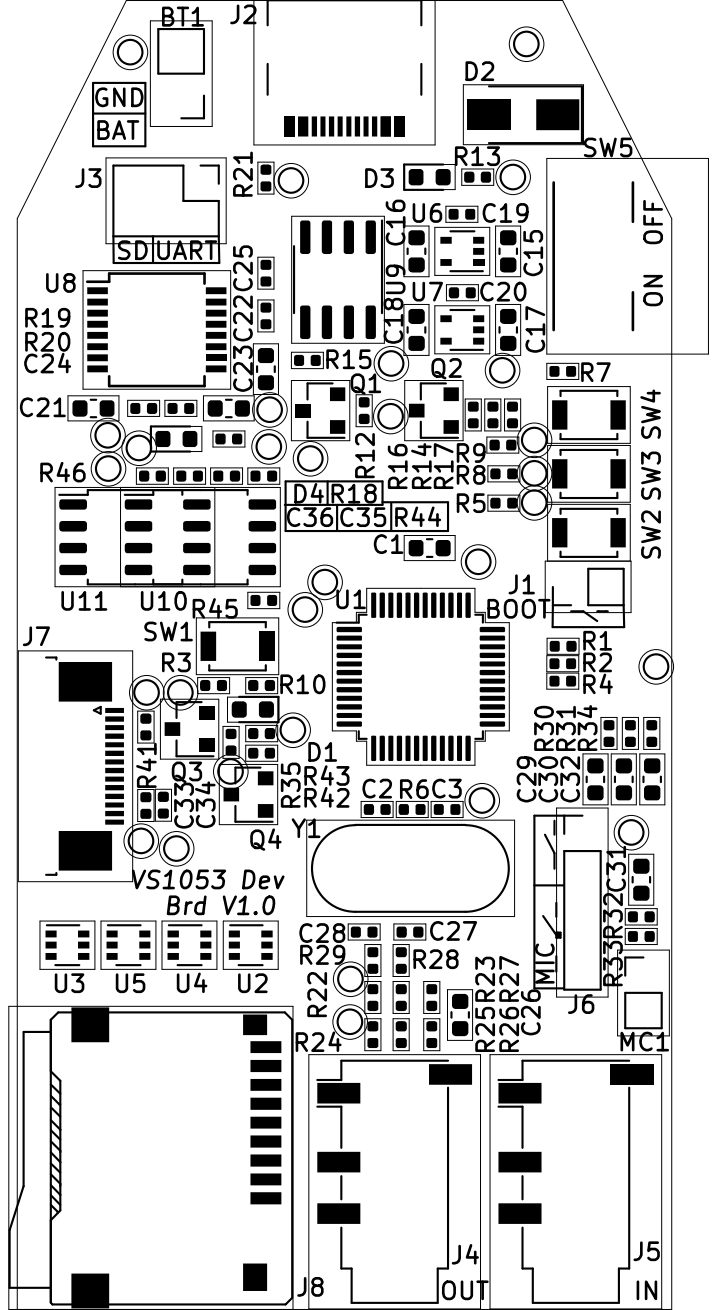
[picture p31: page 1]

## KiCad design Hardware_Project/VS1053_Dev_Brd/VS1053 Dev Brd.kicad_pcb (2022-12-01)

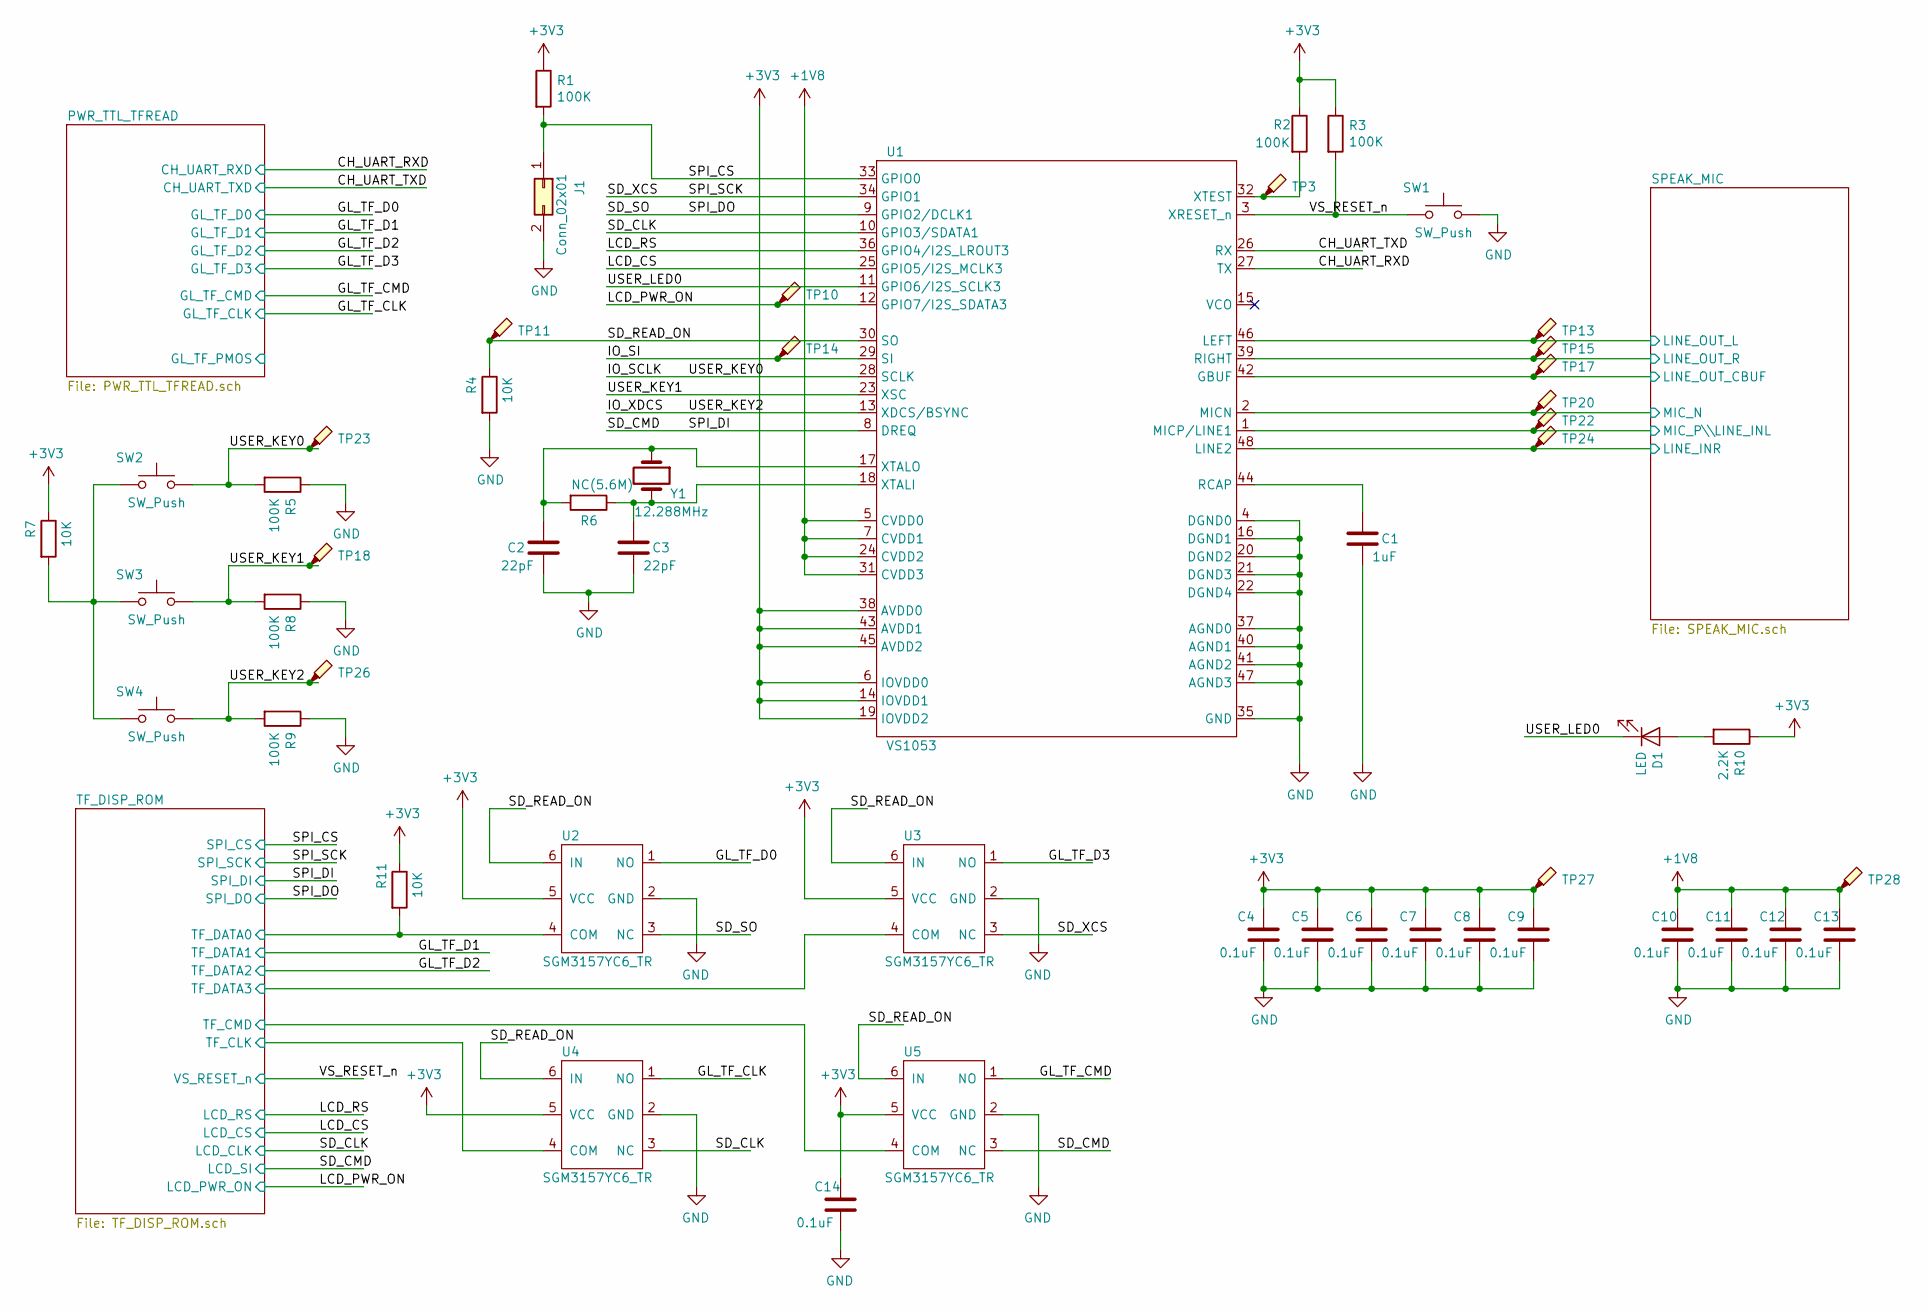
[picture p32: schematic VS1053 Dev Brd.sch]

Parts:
C1: 1uF; C_0603_1608Metric
C2, C3: 22pF; C_0402_1005Metric
C4, C5, C6, C7, C8, C9, C10, C11, C12, C13, C14: 0.1uF; C_0402_1005Metric
D1: LED; D_0603_1608Metric
J1: Conn_02x01; PinHeader_1x02_P2.00mm_Vertical
R1, R2, R3, R5, R8, R9: 100K; R_0402_1005Metric
R4, R7, R11: 10K; R_0402_1005Metric
R6: NC(5.6M); R_0402_1005Metric
R10: 2.2K; R_0402_1005Metric
SW1, SW2, SW3, SW4: SW_Push; SW_SPST_B3U-1000P
TP3, TP10, TP11, TP13, TP14, TP15, TP17, TP18, TP20, TP22, TP23, TP24, TP26, TP27, TP28: TestPoint_Probe; TestPoint_Pad_D1.0mm
U1: VS1053; LQFP-48_7x7mm_P0.5mm
U2, U3, U4, U5: SGM3157YC6_TR; SOT-363_SC-70-6
Y1: 12.288MHz; Crystal_HC49-4H_Vertical

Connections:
+1V8: C10.1, C11.1, C12.1, C13.1, TP28.1, U1.5 (CVDD0), U1.7 (CVDD1), U1.24 (CVDD2), U1.31 (CVDD3); also elsewhere on the board
+3V3: C4.1, C5.1, C6.1, C7.1, C8.1, C9.1, C14.1, R1.1, R2.1, R3.1, R7.1, R10.1, R11.1, TP27.1, U1.6 (IOVDD0), U1.14 (IOVDD1), U1.19 (IOVDD2), U1.38 (AVDD0), U1.43 (AVDD1), U1.45 (AVDD2), U2.5 (VCC), U3.5 (VCC), U4.5 (VCC), U5.5 (VCC); also elsewhere on the board
/CH_UART_RXD: U1.27 (TX); also elsewhere on the board
/CH_UART_TXD: U1.26 (RX); also elsewhere on the board
/GL_TF_CLK: U4.1 (NO); also elsewhere on the board
/GL_TF_CMD: U5.1 (NO); also elsewhere on the board
/GL_TF_D0: U2.1 (NO); also elsewhere on the board
/GL_TF_D3: U3.1 (NO); also elsewhere on the board
/IO_SCLK: R5.2, SW2.2, TP23.1, U1.28 (SCLK)
/IO_SI: TP14.1, U1.29 (SI)
/IO_XDCS: R9.2, SW4.2, TP26.1, U1.13 (XDCS/BSYNC)
/LCD_CS: U1.25 (GPIO5/I2S_MCLK3); also elsewhere on the board
/LCD_PWR_ON: TP10.1, U1.12 (GPIO7/I2S_SDATA3); also elsewhere on the board
/LCD_RS: U1.36 (GPIO4/I2S_LROUT3); also elsewhere on the board
/SD_CLK: U1.10 (GPIO3/SDATA1), U4.3 (NC); also elsewhere on the board
/SD_CMD: U1.8 (DREQ), U5.3 (NC); also elsewhere on the board
/SD_READ_ON: R4.1, TP11.1, U1.30 (SO), U2.6 (IN), U3.6 (IN), U4.6 (IN), U5.6 (IN)
/SD_SO: U1.9 (GPIO2/DCLK1), U2.3 (NC); also elsewhere on the board
/SD_XCS: U1.34 (GPIO1), U3.3 (NC); also elsewhere on the board
/SPEAK_MIC/LINE_INR: TP24.1, U1.48 (LINE2); also elsewhere on the board
/SPEAK_MIC/LINE_OUT_CBUF: TP17.1, U1.42 (GBUF); also elsewhere on the board
/SPEAK_MIC/LINE_OUT_L: TP13.1, U1.46 (LEFT); also elsewhere on the board
/SPEAK_MIC/LINE_OUT_R: TP15.1, U1.39 (RIGHT); also elsewhere on the board
/SPEAK_MIC/MIC_N: TP20.1, U1.2 (MICN); also elsewhere on the board
/SPEAK_MIC/MIC_P\LINE_INL: TP22.1, U1.1 (MICP/LINE1); also elsewhere on the board
/SPI_CS: J1.1, R1.2, U1.33 (GPIO0); also elsewhere on the board
/TF_DISP_ROM/TF_CLK: U4.4 (COM); also elsewhere on the board
/TF_DISP_ROM/TF_CMD: U5.4 (COM); also elsewhere on the board
/TF_DISP_ROM/TF_DATA0: R11.2, U2.4 (COM); also elsewhere on the board
/TF_DISP_ROM/TF_DATA3: U3.4 (COM); also elsewhere on the board
/USER_KEY1: R8.2, SW3.2, TP18.1, U1.23 (XSC)
/USER_LED0: D1.1 (K), U1.11 (GPIO6/I2S_SCLK3)
/VS_RESET_n: R3.2, SW1.1, U1.3 (XRESET_n); also elsewhere on the board
GND: C1.2, C2.1, C3.2, C4.2, C5.2, C6.2, C7.2, C8.2, C9.2, C10.2, C11.2, C12.2, C13.2, C14.2, J1.2, R4.2, R5.1, R8.1, R9.1, SW1.2, U1.4 (DGND0), U1.16 (DGND1), U1.20 (DGND2), U1.21 (DGND3), U1.22 (DGND4), U1.35 (GND), U1.37 (AGND0), U1.40 (AGND1), U1.41 (AGND2), U1.47 (AGND3), U2.2 (GND), U3.2 (GND), U4.2 (GND), U5.2 (GND); also elsewhere on the board
unnamed: C1.1, U1.44 (RCAP)
unnamed: C2.2, R6.2, U1.17 (XTALO), Y1.1
unnamed: C3.1, R6.1, U1.18 (XTALI), Y1.2
unnamed: D1.2 (A), R10.2
unnamed: R2.2, TP3.1, U1.32 (XTEST)
unnamed: R7.2, SW2.1, SW3.1, SW4.1

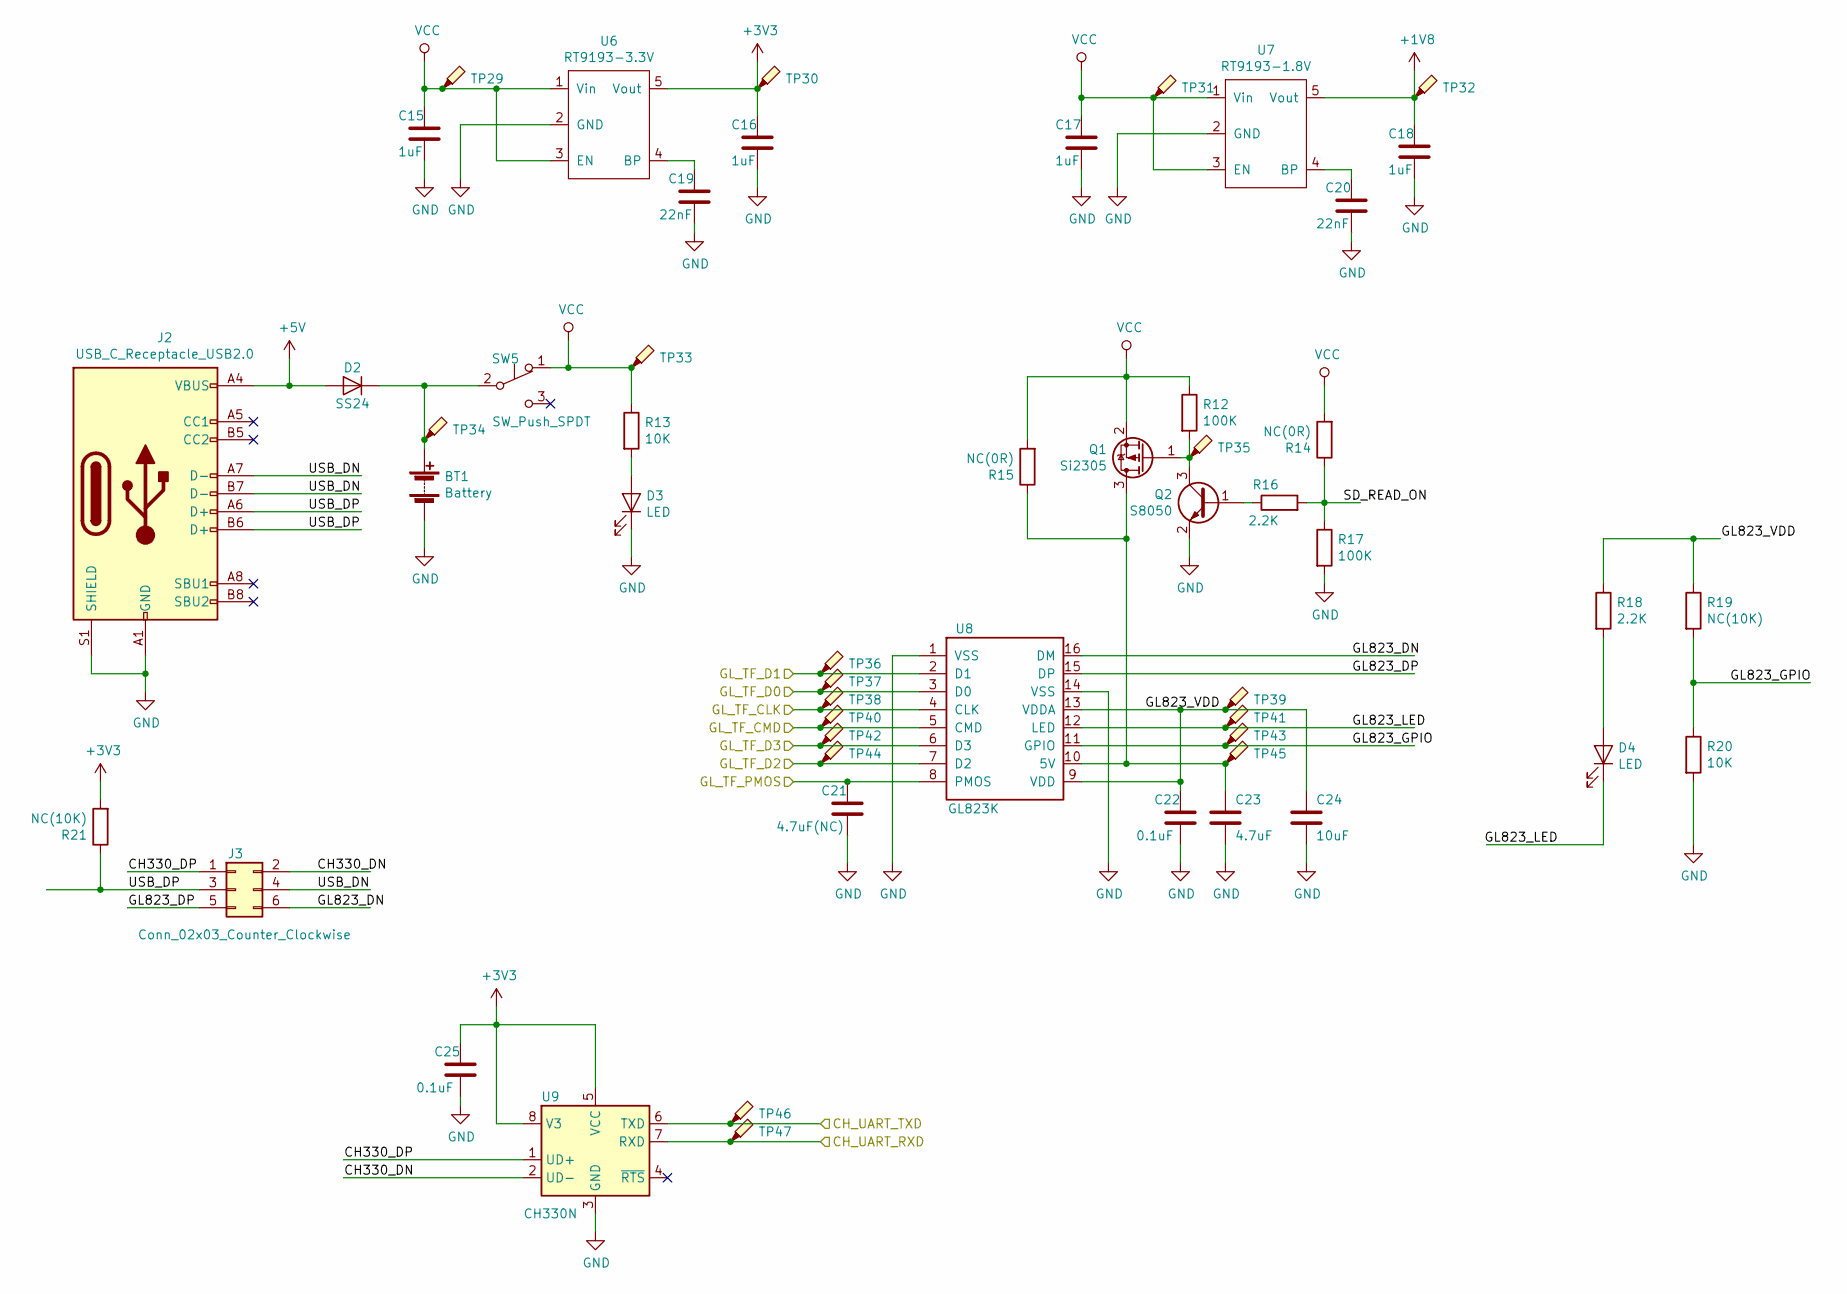
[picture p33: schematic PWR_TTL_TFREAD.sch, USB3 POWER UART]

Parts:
BT1: Battery; PinHeader_1x02_P2.54mm_Vertical
C15, C16, C17, C18: 1uF; C_0603_1608Metric
C19, C20: 22nF; C_0402_1005Metric
C21: 4.7uF(NC); C_0603_1608Metric
C22, C25: 0.1uF; C_0402_1005Metric
C23: 4.7uF; C_0603_1608Metric
C24: 10uF; C_0603_1608Metric
D2: SS24; D_SMA
D3, D4: LED; D_0603_1608Metric
J2: USB_C_Receptacle_USB2.0; USB_C_Receptacle_Palconn_UTC16-G
J3: Conn_02x03_Counter_Clockwise; PinHeader_2x03_P2.00mm_Vertical
Q1: Si2305; SOT-23
Q2: S8050; SOT-23
R12, R17: 100K; R_0402_1005Metric
R13, R20: 10K; R_0402_1005Metric
R14, R15: NC(0R); R_0402_1005Metric
R16, R18: 2.2K; R_0402_1005Metric
R19, R21: NC(10K); R_0402_1005Metric
SW5: SW_Push_SPDT; SW_CuK_OS102011MA1QN1_SPDT_Angled
TP29, TP30, TP31, TP32, TP33, TP34, TP35, TP36, TP37, TP38, TP39, TP40, TP41, TP42, TP43, TP44, TP45, TP46, TP47: TestPoint_Probe; TestPoint_Pad_D1.0mm
U6: RT9193-3.3V; SOT-353_SC-70-5
U7: RT9193-1.8V; SOT-353_SC-70-5
U8: GL823K; SSOP-16_5.3x6.2mm_P0.65mm
U9: CH330N; SOIC-8_3.9x4.9mm_P1.27mm

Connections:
+1V8: C18.1, TP32.1, U7.5 (Vout); also elsewhere on the board
+3V3: C16.1, C25.1, R21.2, TP30.1, U6.5 (Vout), U9.5 (VCC), U9.8 (V3); also elsewhere on the board
+5V: D2.2 (A), J2.A4 (VBUS), J2.A9 (VBUS), J2.B4 (VBUS), J2.B9 (VBUS)
/CH_UART_RXD: TP47.1, U9.7 (RXD); also elsewhere on the board
/CH_UART_TXD: TP46.1, U9.6 (TXD); also elsewhere on the board
/GL_TF_CLK: TP38.1, U8.4 (CLK); also elsewhere on the board
/GL_TF_CMD: TP40.1, U8.5 (CMD); also elsewhere on the board
/GL_TF_D0: TP37.1, U8.3 (D0); also elsewhere on the board
/GL_TF_D1: TP36.1, U8.2 (D1); also elsewhere on the board
/GL_TF_D2: TP44.1, U8.7 (D2); also elsewhere on the board
/GL_TF_D3: TP42.1, U8.6 (D3); also elsewhere on the board
/PWR_TTL_TFREAD/CH330_DN: J3.2 (Pin_6), U9.2 (UD-)
/PWR_TTL_TFREAD/CH330_DP: J3.1, U9.1 (UD+)
/PWR_TTL_TFREAD/GL823_DN: J3.6 (Pin_4), U8.16 (DM)
/PWR_TTL_TFREAD/GL823_DP: J3.5 (Pin_3), U8.15 (DP)
/PWR_TTL_TFREAD/GL823_GPIO: R19.2, R20.1, TP43.1, U8.11 (GPIO)
/PWR_TTL_TFREAD/GL823_LED: D4.1 (K), TP41.1, U8.12 (LED)
/PWR_TTL_TFREAD/GL823_VDD: C22.1, C24.1, R18.1, R19.1, TP39.1, U8.9 (VDD), U8.13 (VDDA)
/PWR_TTL_TFREAD/GL_TF_PMOS: C21.1, U8.8 (PMOS)
/PWR_TTL_TFREAD/SD_READ_ON: R14.1, R16.2, R17.1
/PWR_TTL_TFREAD/USB_DN: J2.A7 (D-), J2.B7 (D-), J3.4 (Pin_5)
/PWR_TTL_TFREAD/USB_DP: J2.A6 (D+), J2.B6 (D+), J3.3 (Pin_2), R21.1
GND: BT1.2 (-), C15.2, C16.2, C17.2, C18.2, C19.2, C20.2, C21.2, C22.2, C23.2, C24.2, C25.2, D3.1 (K), J2.A1 (GND), J2.A12 (GND), J2.B1 (GND), J2.B12 (GND), J2.S1 (SHIELD), Q2.2 (E), R17.2, R20.2, U6.2 (GND), U7.2 (GND), U8.1 (VSS), U8.14 (VSS), U9.3 (GND); also elsewhere on the board
unnamed: BT1.1 (+), D2.1 (K), SW5.2 (B), TP34.1
unnamed: C19.1, U6.4 (BP)
unnamed: C20.1, U7.4 (BP)
unnamed: C23.1, Q1.3 (D), R15.1, TP45.1, U8.10 (5V)
unnamed: D3.2 (A), R13.2
unnamed: D4.2 (A), R18.2
unnamed: Q1.1 (G), Q2.3 (C), R12.2, TP35.1
unnamed: Q2.1 (B), R16.1
VCC: C15.1, C17.1, Q1.2 (S), R12.1, R13.1, R14.2, R15.2, SW5.1 (A), TP29.1, TP31.1, TP33.1, U6.1 (Vin), U6.3 (EN), U7.1 (Vin), U7.3 (EN); also elsewhere on the board

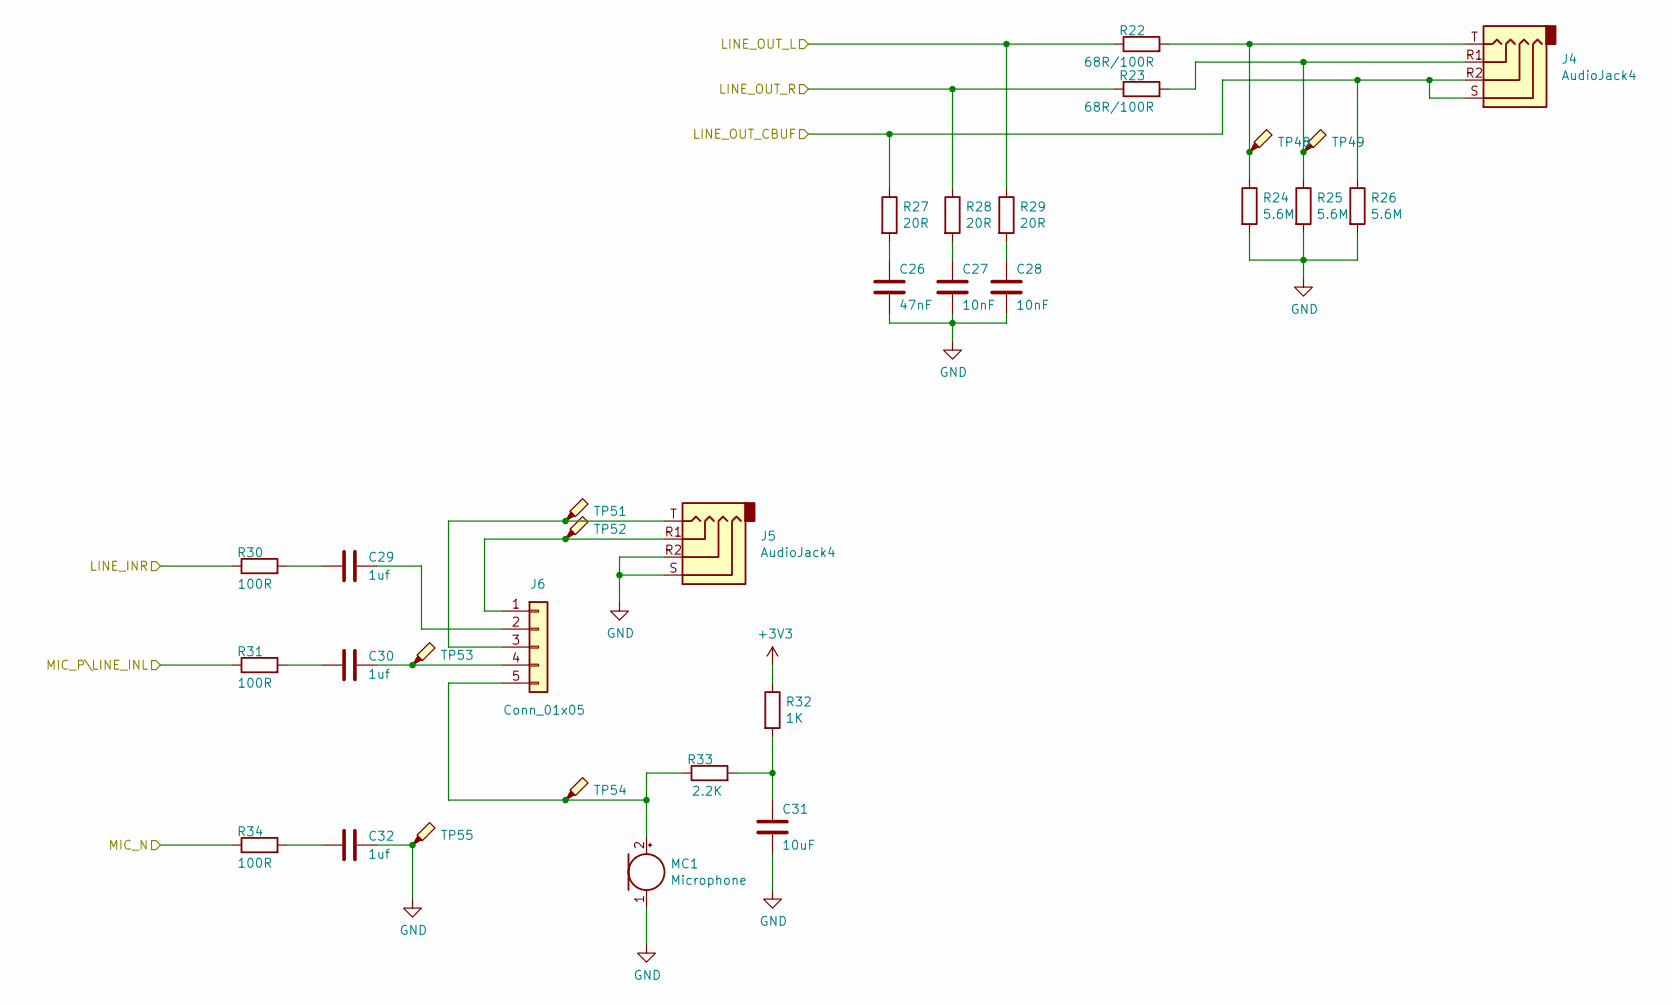
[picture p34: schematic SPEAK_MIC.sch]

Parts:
C26: 47nF; C_0603_1608Metric
C27, C28: 10nF; C_0402_1005Metric
C29, C30, C32: 1uf; C_0603_1608Metric
C31: 10uF; C_0603_1608Metric
J4, J5: AudioJack4; Jack_3.5mm_PJ320D_Horizontal
J6: Conn_01x05; PinHeader_1x05_P2.00mm_Vertical
MC1: Microphone; PinHeader_1x02_P2.00mm_Vertical
R22, R23: 68R/100R; R_0402_1005Metric
R24, R25, R26: 5.6M; R_0402_1005Metric
R27, R28, R29: 20R; R_0402_1005Metric
R30, R31, R34: 100R; R_0402_1005Metric
R32: 1K; R_0402_1005Metric
R33: 2.2K; R_0402_1005Metric
TP48, TP49, TP51, TP52, TP53, TP54, TP55: TestPoint_Probe; TestPoint_Pad_D1.0mm

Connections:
+3V3: R32.1; also elsewhere on the board
/SPEAK_MIC/LINE_INR: R30.1; also elsewhere on the board
/SPEAK_MIC/LINE_OUT_CBUF: J4.R2, J4.S, R26.1, R27.1; also elsewhere on the board
/SPEAK_MIC/LINE_OUT_L: R22.1, R29.1; also elsewhere on the board
/SPEAK_MIC/LINE_OUT_R: R23.1, R28.1; also elsewhere on the board
/SPEAK_MIC/MIC_N: R34.1; also elsewhere on the board
/SPEAK_MIC/MIC_P\LINE_INL: R31.1; also elsewhere on the board
GND: C26.2, C27.2, C28.2, C31.2, C32.2, J5.R2, J5.S, MC1.1 (-), R24.2, R25.2, R26.2, TP55.1; also elsewhere on the board
unnamed: C26.1, R27.2
unnamed: C27.1, R28.2
unnamed: C28.1, R29.2
unnamed: C29.1, R30.2
unnamed: C29.2, J6.2
unnamed: C30.1, R31.2
unnamed: C30.2, J6.4, TP53.1
unnamed: C31.1, R32.2, R33.2
unnamed: C32.1, R34.2
unnamed: J4.R1, R23.2, R25.1, TP49.1
unnamed: J4.T, R22.2, R24.1, TP48.1
unnamed: J5.R1, J6.1, TP52.1
unnamed: J5.T, J6.3, TP51.1
unnamed: J6.5, MC1.2 (+), R33.1, TP54.1

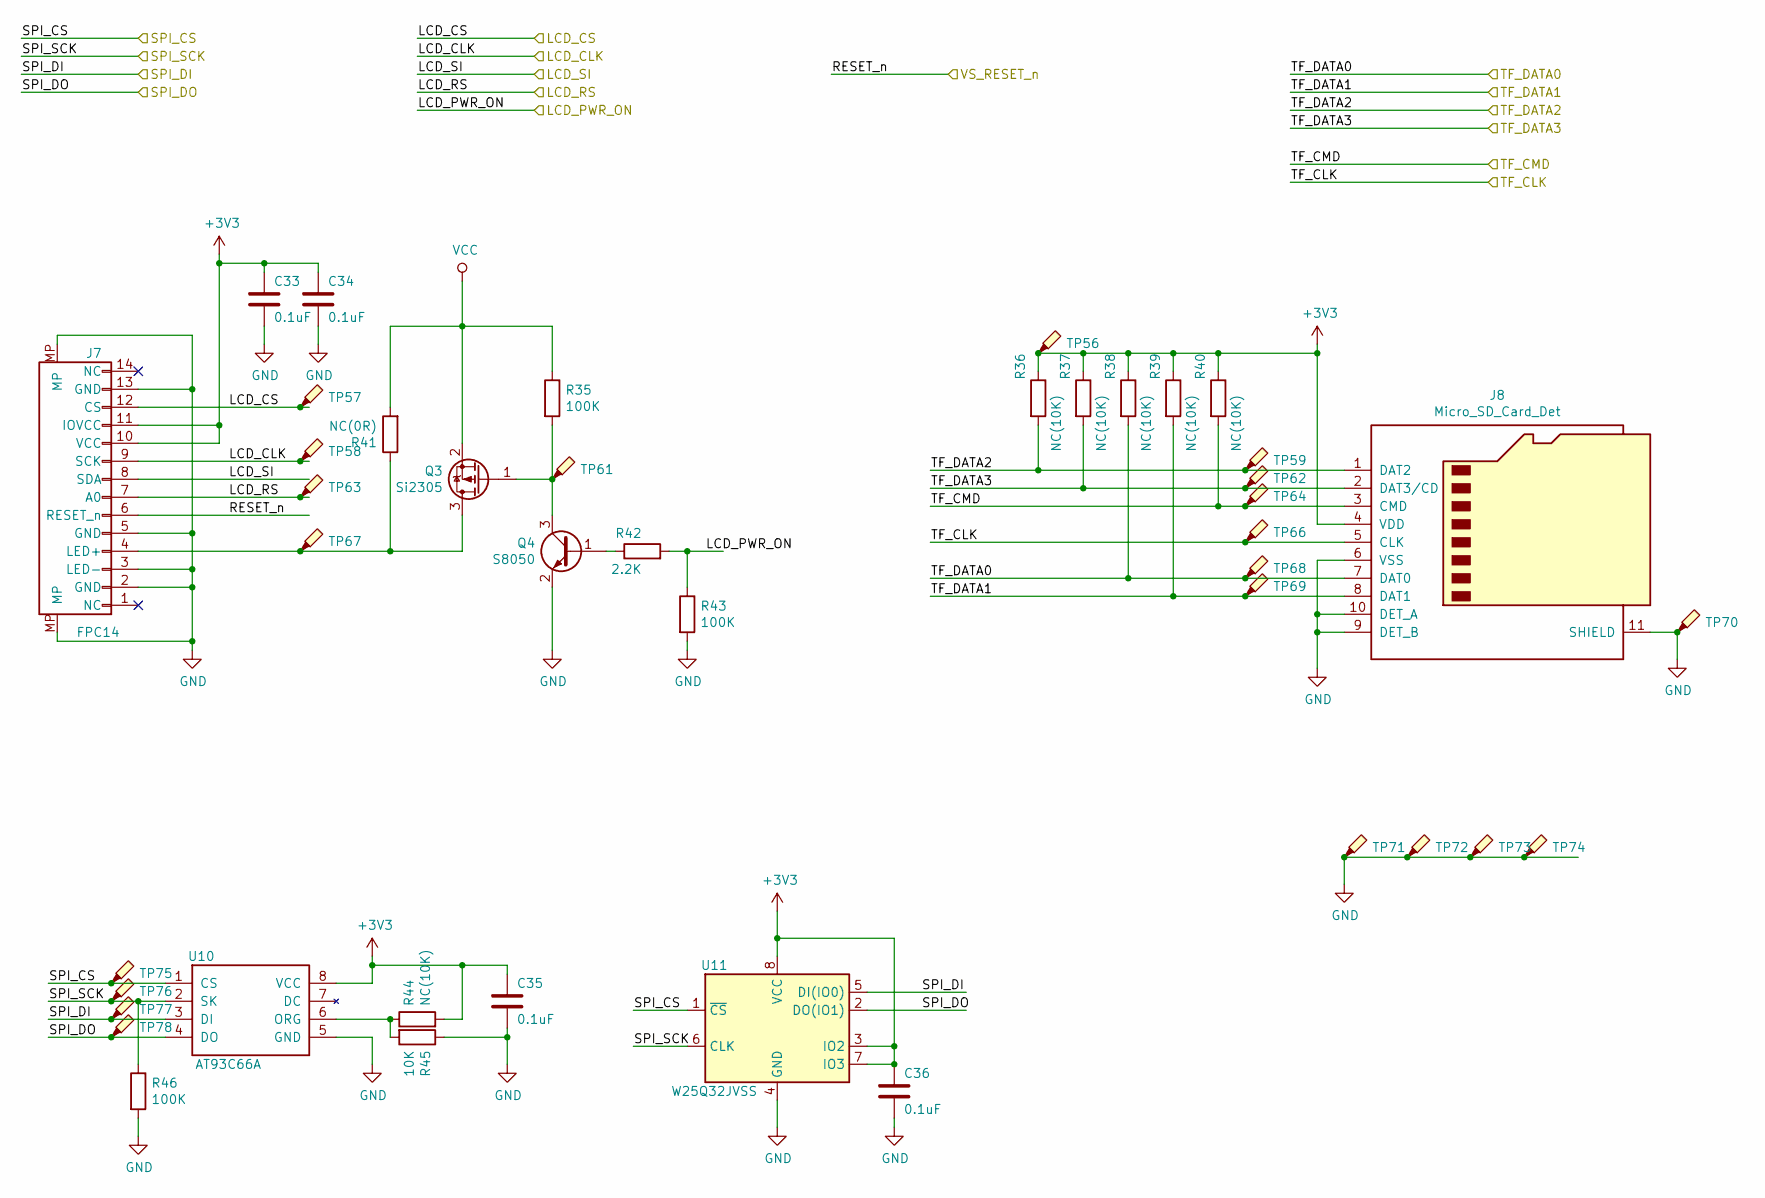
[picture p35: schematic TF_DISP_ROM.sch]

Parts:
C33, C34, C35, C36: 0.1uF; C_0402_1005Metric
J7: FPC14; TE_1-1734839-4_1x14-1MP_P0.5mm_Horizontal
J8: Micro_SD_Card_Det; SD-MINI-X
Q3: Si2305; SOT-23
Q4: S8050; SOT-23
R35, R43, R46: 100K; R_0402_1005Metric
R36, R37, R38, R39, R40, R44: NC(10K); R_0402_1005Metric
R41: NC(0R); R_0402_1005Metric
R42: 2.2K; R_0402_1005Metric
R45: 10K; R_0402_1005Metric
TP56, TP57, TP58, TP59, TP61, TP62, TP63, TP64, TP66, TP67, TP68, TP69, TP70, TP71, TP72, TP73, TP74, TP75, TP76, TP77, TP78: TestPoint_Probe; TestPoint_Pad_D1.0mm
U10: AT93C66A; SOIC-8_5.275x5.275mm_P1.27mm
U11: W25Q32JVSS; SOIC-8_5.275x5.275mm_P1.27mm

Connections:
+3V3: C33.1, C34.1, C35.1, C36.1, J7.10 (VCC), J7.11 (IOVCC), J8.4 (VDD), R36.1, R37.1, R38.1, R39.1, R40.1, R44.2, TP56.1, U10.8 (VCC), U11.3 (IO2), U11.7 (IO3), U11.8 (VCC); also elsewhere on the board
/GL_TF_D1: J8.8 (DAT1), R39.2, TP69.1; also elsewhere on the board
/GL_TF_D2: J8.1 (DAT2), R36.2, TP59.1; also elsewhere on the board
/LCD_CS: J7.12 (CS), TP57.1; also elsewhere on the board
/LCD_PWR_ON: R42.2, R43.1; also elsewhere on the board
/LCD_RS: J7.7 (A0), TP63.1; also elsewhere on the board
/SD_CLK: J7.9 (SCK), TP58.1; also elsewhere on the board
/SD_CMD: J7.8 (SDA), TP77.1, U10.3 (DI), U11.5 (DI(IO0)); also elsewhere on the board
/SD_SO: TP78.1, U10.4 (DO), U11.2 (DO(IO1)); also elsewhere on the board
/SD_XCS: R46.1, TP76.1, U10.2 (SK), U11.6 (CLK); also elsewhere on the board
/SPI_CS: TP75.1, U10.1 (CS), U11.1 (~CS); also elsewhere on the board
/TF_DISP_ROM/TF_CLK: J8.5 (CLK), TP66.1; also elsewhere on the board
/TF_DISP_ROM/TF_CMD: J8.3 (CMD), R40.2, TP64.1; also elsewhere on the board
/TF_DISP_ROM/TF_DATA0: J8.7 (DAT0), R38.2, TP68.1; also elsewhere on the board
/TF_DISP_ROM/TF_DATA3: J8.2 (DAT3/CD), R37.2, TP62.1; also elsewhere on the board
/VS_RESET_n: J7.6 (RESET_n); also elsewhere on the board
GND: C33.2, C34.2, C35.2, C36.2, J7.2 (GND), J7.3 (LED-), J7.5 (GND), J7.13 (GND), J7.MP, J8.6 (VSS), J8.9 (DET_B), J8.10 (DET_A), J8.11 (SHIELD), Q4.2 (E), R43.2, R45.1, R46.2, TP70.1, TP71.1, TP72.1, TP73.1, TP74.1, U10.5 (GND), U11.4 (GND); also elsewhere on the board
unnamed: J7.4 (LED+), Q3.3 (D), R41.1, TP67.1
unnamed: Q3.1 (G), Q4.3 (C), R35.2, TP61.1
unnamed: Q4.1 (B), R42.1
unnamed: R44.1, R45.2, U10.6 (ORG)
VCC: Q3.2 (S), R35.1, R41.2; also elsewhere on the board

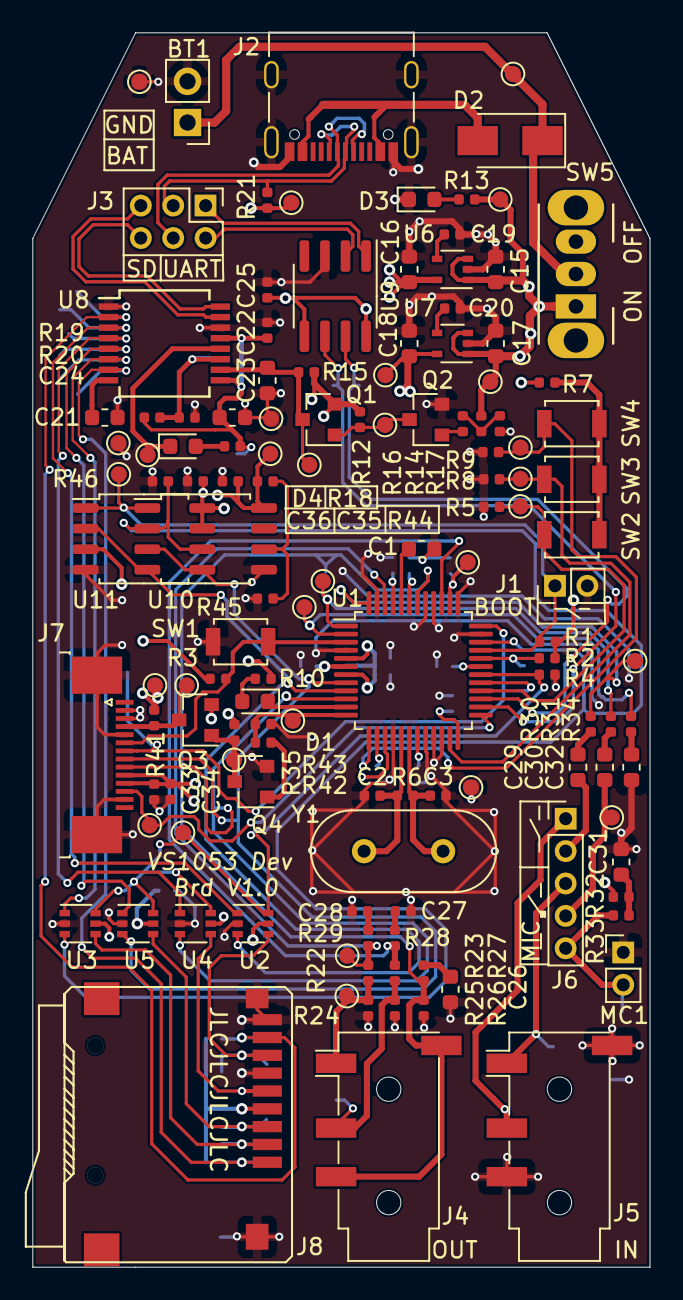
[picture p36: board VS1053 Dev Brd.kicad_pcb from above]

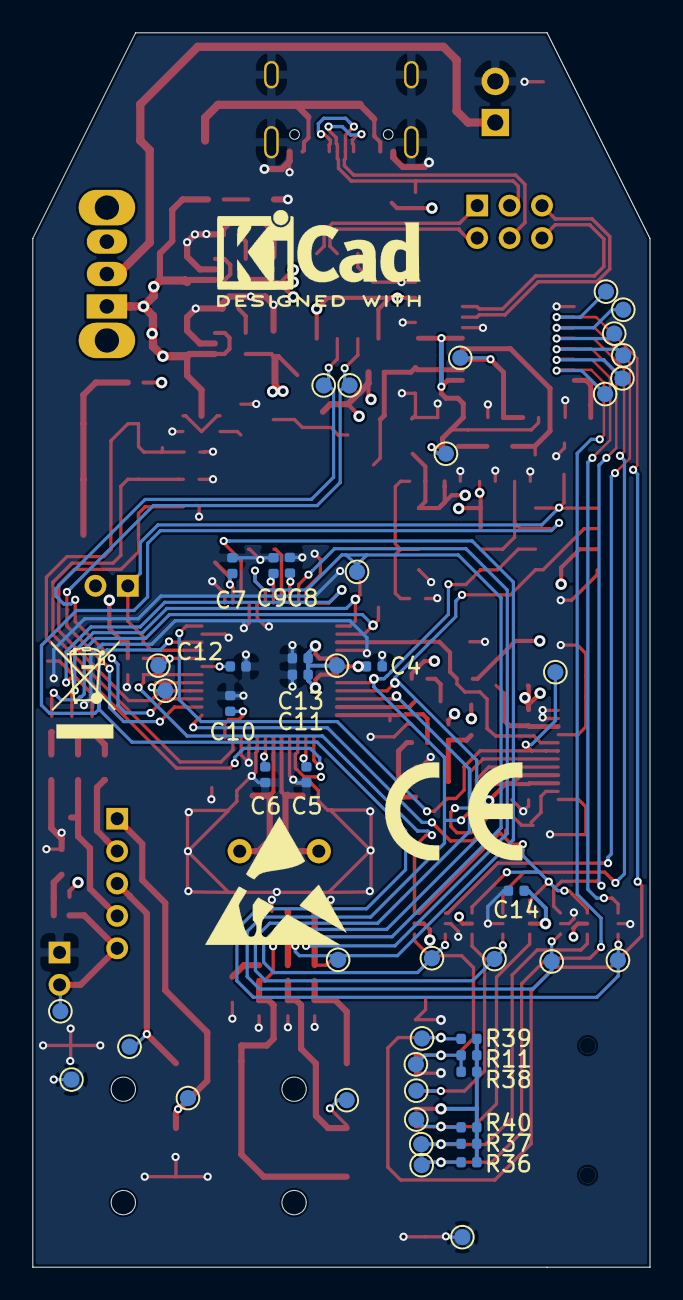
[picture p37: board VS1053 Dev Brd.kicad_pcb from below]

Board: 4 copper layers, 38.1 x 76.2 mm, 179 parts (49 on the bottom side), 81 nets.

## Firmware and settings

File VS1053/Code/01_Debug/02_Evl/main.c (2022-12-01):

/* For free support for VSIDE, please visit www.vsdsp-forum.com */

/*	VS8051/VS1053/VS1063 Developer Board LCD + Audio In, Audio Out Template

	This is an audio in + audio out + LCD display template for the
    V S 8 0 5 3  /  V S 1 0 5 3  /  V S 1 0 6 3  D E V E L O P E R  B O A R D.
	It is useful for developing	signal processing filter software. 
	
	Insert your audio filter code into the interrupt handler in audioint.c.
	The default example "filter" in this template is a "boost by -12dB / -6dB
	/ 0dB / +6dB / +12dB filter" and you can select the boosting with the
	top-right button on the developer board.
	
	Additionally this example configures the onboard FM tuner (TEA5767) to
	89.0 MHz, and you can change the frequency by using the center-left, 
	center-right, bottom-left and bottom-right buttons.
	
	You can use the jumper array on the left side of the LCD screen to
	select which inputs to route to the left and right line inputs.
	
 	LINE IN		FM		BAT+MIC (battery monitor + microphone)	
		
	  	 .			 .			 #
		 .			 .			 #
		.##			##.			...
		.##			##.			.#.
		 .			 .			 #

	You can use the JP3 to select the FM antenna:
	- To use the headphone wire as the antenna, set jumper to the HP-ANT side
	- To use external antenna, connect antenna to the center pin and antenna
	  ground to the right pin.  (For a really simple antenna, you can even
	  connect a short length of wire to the center pin of JP13.)

	Note that there is currently no software to activate the MIC AMPLIFIER,
	if you use the microphone, please activate the microphone amplifier
	in the SCI_MODE register.
	
	The board also contains a SD card slot, USB SD reader IC and an untested
	early VS23S010A sample test IC (1 megabit, 128 kilobyte SPI RAM). There is 
	no software support for these features at the time of writing this readme.
	
	To load: 
	- Keep BOOT SELECT and POWER buttons pressed, press RESET
	- Release BOOT SELECT and POWER buttons, Power LED should be on
	- Press the "Run" button in VSIDE, specify UART parameters as necessary
	- After loading, press "Stop" button in VSIDE to avoid hang-ups..
	
	To flash to SPI flash:
	- You need to select the "SST25xxB Compatible" prommer module
	  from Project -> Prommer/Flasher Utility
	  

   User Interface:

   --------------+-----------------+----------------                    
    POWER ON     |    VOLUME +     |  BOOST SELECT
   --------------+-----------------+----------------
    FM Tune -50k |                 |  FM Tune +50k
   --------------+-----------------+----------------
    FM Tune -1M  |    VOLUME -     |  FM Tune +1M
   --------------+-----------------+----------------


*/
#ifdef VS1063
#include <vs1063.h>
#else
#include <vs1053.h>
#endif
#include "devboard.h"
#include "audioint.h"
#include "lcd.h"
#include "soundpressure.h"
#include "sdm_beep.h"
#include "smallnumbers.h"
#include "buttons.h"
#include "fmtuner.h"
#include "dacvolume.h"
#include "numberstrings.h"

u_int16 outLevels[2]={0};
u_int16 inLevels[2]={0};
u_int16 fm_freq = 8900; //89.00 MHz
s_int16 dacVolume;


void ScreenUpdate() {
	lcd0.x = 10; 
	lcd0.y = 10;
	LcdPutString("Volume: ");
	LcdPutString(IntToString(dacVolume,0));
	LcdPutString(" dB  ");

	lcd0.x = 10;
	lcd0.y = 20;
	LcdPutString("FM: ");
	LcdPutString(IntToStr(fm_freq,2));
	LcdPutString(" MHz  ");

	lcd0.x = 10;
	lcd0.y = 30;
	LcdPutString("Boost: ");
	LcdPutString(IntToString(boostShift*6,0));
	LcdPutString(" dB  ");
}

void ScreenRefresh(){
	LcdFilledRectangle(0,0,159,127,0,lcd0.backgroundColor);	
	LcdFilledRectangle(5,3,154,38,0,COLOR_SHADOW);
	LcdFilledRectangle(6,4,154,38,0,COLOR_GRAY);
	lcd0.textColor = COLOR_SHADOW;	
	lcd0.originY = 42;
	DrawSoundPressureArea();
	lcd0.x = 2; lcd0.y = 5;
	PutSmallGlyph(0x4904);//i
	PutSmallGlyph(0x5ac0);//n
	lcd0.originY = 85;
	lcd0.x = 2; lcd0.y = 5;
	PutSmallGlyph(0x7bc0);//o
	PutSmallGlyph(0x7b40);//u
	PutSmallGlyph(0x72c9);//t
	DrawSoundPressureArea();
	lcd0.textColor = __RGB565RGB(64,64,64);
	lcd0.backgroundColor = COLOR_GRAY;
	lcd0.originY = 0;
	dacVolume = 0;
	SetDacVolume(dacVolume);
	ScreenUpdate();
}

main() {
	// Initialize the developer board hardware
	USEX(SCI_CLOCKF) = CORE_CLOCK_3X;
	InitHardware(); // Basic chip initialization, resets UART speed to 9600bps
	USEX(SCI_VOL) = 0x0000;
	USEX(GPIO_DDR) = ~(1 << 2); // ALL GPIO IS OUTPUT EXCEPT 2(MISO)
	USEX(GPIO_ODATA) = ~(1 << 2); // ALL GPIO IS OUTPUT EXCEPT 2(MISO)	
	LcdDelay(1000);
	USEX(DAC_LEFT) = 0;
	USEX(DAC_RIGHT) = 0;
	USEX(SCI_STATUS) &= ~(1<<SCIST_APDOWN1); // Switch on analog power 
	LcdDelay(1000);	
	USEX(SCI_STATUS) &= ~(1<<SCIST_APDOWN2); // Switch on analog driver
	
	// Show text in VSIDE console (requires emulator UART connection)
	// puts("Hello, world."); // If you uncomment this, you CANNOT prom 
	// it to SPI flash and expect it to boot properly.

	LcdInit(0);
	ScreenRefresh();
	I2CSetFM(fm_freq);

	// Start the audio interrupt (Line In -> Line Out)
	InitAudioPath();
	// Init the SDM Beeper
	SDMBeepInit();

	while(1) {		
		// Main Loop
		if (sampleCounter16 > 200) {
			u_int16 key;

			sampleCounter16 = 0;			
			lcd0.originY = 42; DrawSoundPressureBars(stereoSampleIn,inLevels);
			lcd0.originY = 85; DrawSoundPressureBars(stereoSampleOut,outLevels);	
			lcd0.originY = 0;

			key = GetKeyPress();
			if (key) {
				beepLength = 512;				
				switch(key) {
					case SW_LEFT: {
						fm_freq -= 5;
						I2CSetFM(fm_freq);
						break;
					}
					case SW_RIGHT: {
						fm_freq += 5;
						I2CSetFM(fm_freq);
						break;
					}
					case SW_STOP: {
						fm_freq -= 100;
						I2CSetFM(fm_freq);
						break;
					}
					case SW_PLAY: {
						fm_freq += 100;
						I2CSetFM(fm_freq);
						break;
					}
					case SW_DOWN: {
						dacVolume--;
						SetDacVolume(dacVolume);
						break;
					}
					case SW_UP:	{
						if (dacVolume < 0) {
							dacVolume++;
						}
						SetDacVolume(dacVolume);
						break;
					}
					case SW_REC: {
						boostShift++;
						if (boostShift > 2) {
							boostShift = -2;
						}
					}
				}
				ScreenUpdate();
			}	
		}	
	}	
}

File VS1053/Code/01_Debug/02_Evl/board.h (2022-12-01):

#ifndef __BOARD_H__
#define __BOARD_H__

#include <gpio.h>


// some hardware-specific defines for VS1053 prototyping boards.
//
// define ONE of the following before including this file
// ~~~~~~~~~~~~~~~~~~~~~~~~~~~~~~~~
//
// USE_PROTOTYPING_BOARD -- VS10XX prototyping board
// USE_SIMPLE_DSP_BOARD -- "simple DSP" with host board


//
// --------- DEFINITIONS FOR VS1053 SIMPLE DSP BOARD ------------
//
#ifdef USE_SIMPLE_DSP_BOARD

#define BUTTON_1 (1 << 3) /* Button 1 is at GPIO3 */
#define BUTTON_1_PRESSED GPIO_IS_HIGH(BUTTON_1)
#define CONFIGURE_BUTTON_1 {GPIO_CONFIGURE_AS_INPUT(BUTTON_1);}

#define LED_1 (1 << 4) /* Led 1 is at GPIO4 */
#define LED_2 (1 << 5) /* Led 2 is at GPIO5 */
#define LED_3 (1 << 6) /* Led 3 is at GPIO6 */
#define LED_4 (1 << 7) /* Led 4 is at GPIO7 */

#define SET_LED_1_ON GPIO_SET_HIGH(LED_1)
#define SET_LED_1_OFF GPIO_SET_LOW(LED_1)
#define SET_LED_2_ON GPIO_SET_HIGH(LED_2)
#define SET_LED_2_OFF GPIO_SET_LOW(LED_2)
#define SET_LED_3_ON GPIO_SET_HIGH(LED_3)
#define SET_LED_3_OFF GPIO_SET_LOW(LED_3)
#define SET_LED_4_ON GPIO_SET_HIGH(LED_4)
#define SET_LED_4_OFF GPIO_SET_LOW(LED_4)

#define CONFIGURE_LED_1 {GPIO_CONFIGURE_AS_OUTPUT(LED_1);}
#define CONFIGURE_LED_2 {GPIO_CONFIGURE_AS_OUTPUT(LED_2);}
#define CONFIGURE_LED_3 {GPIO_CONFIGURE_AS_OUTPUT(LED_3);}
#define CONFIGURE_LED_4 {GPIO_CONFIGURE_AS_OUTPUT(LED_4);}
#define CONFIGURE_LEDS {GPIO_CONFUGURE_AS_OUTPUT(LED_1 | LED_2 | LED_3 | LED_4);}

#endif // USE_SIMPLE_DSP


//
// --------- DEFINITIONS FOR VS1053 PROTOTYPING BOARD ------------
//
#ifdef USE_PROTOTYPING_BOARD

// For historical reasons (same PCB is also used for VS1011 and VS1003), the button
// connections in the prototyping board need to be read in a special way:
#define XDCS_PIN (1 << 11) /* button 1 is at xDCS pin */
#define SI_PIN (1 << 10) /* button 2 is at SI pin and via diode D4 also in xDCS pin */
// (button 3 is more difficult to read in the prototyping board, see schematic.)

#define BUTTON_1_PRESSED ((GPIO_IS_LOW(XDCS_PIN)) && (GPIO_IS_HIGH(SI_PIN)))
#define BUTTON_2_PRESSED (GPIO_IS_LOW(SI_PIN))
#define CONFIGURE_BUTTON_1 {} // No need for configuration, xDCS pin is always input
#define CONFIGURE_BUTTON_2 {} // No need for configuration, xDCS and SI pins are always input

// led 1 is at DREQ pin and DREQ pin is special
#define SET_LED_1_ON DREQ_SET_HIGH
#define SET_LED_1_OFF DREQ_SET_LOW

#define CONFIGURE_LED_1 {} // No need for configuration, DREQ pin is always output
#define CONFIGURE_LEDS {} // No need for configuration, DREQ pin is always output

#endif // USE_PROTOTYPING_BOARD



#endif // __BOARD_H__

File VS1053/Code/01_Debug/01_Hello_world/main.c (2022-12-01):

/* For free support for VSIDE, please visit www.vsdsp-forum.com */

// Please select below which PCB board you use: the Prototyping board
// or the VS1053 Simple DSP board (enabled by default)

#include <stdio.h>
#ifdef VS1063
#include <vs1063.h>
#else
#include <vs1053.h>
#endif

#define USE_PROTOTYPING_BOARD
//#define USE_PROTOTYPING_BOARD
// (define *one* of the PCB types before including board.h)
#include "board.h"

main() {
	// show text in console
	//puts("Hello, world.");
	// set up button and led

	
	GPIO_CONFIGURE_AS_OUTPUT(LED_3);
	GPIO_CONFIGURE_AS_INPUT(XDCS_PIN);
	//
	// enter busy loop, detect button press:
	//
	
	USEX(GPIO_DDR) |= ((1<<8));
	//USEX(GPIO_ODATA) &= (~(1<<9));
	USEX(GPIO_ODATA) |= ((1<<8));

	while (1) {
		if ( (USEX(GPIO_IDATA)) & XDCS_PIN  ) {
			GPIO_SET_HIGH(LED_3);

			USEX(GPIO_DDR) |= ((1<<8));
			//USEX(GPIO_ODATA) &= (~(1<<9));
			USEX(GPIO_ODATA) |= ((1<<8));
			
			//puts("Hello, world.");
		} else {
			GPIO_SET_LOW(LED_3);
			
		}
	}
	return 0;
}

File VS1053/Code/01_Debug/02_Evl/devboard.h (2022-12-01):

/// \file devboard.h I/O Definitions for VS10x3 Developer Board

#ifndef DEVBOARD_H
#define DEVBOARD_H

#define EE_GPIO_PIN_CS 0
#define SPI_PIN_SCLK 1 /*SCLK to EEPROM and SD*/

#define SD_GPIO_PIN_CS 3
#define I2C_GPIO_PIN_SDA 4
#define GPIO_PIN_USB_ACTIVITY 4
#define LCD_GPIO_PIN_CS 5
#define I2C_GPIO_PIN_SCL 6
#define LCD_GPIO_PIN_A0 7
#define LCD_GPIO_PIN_RS LCD_GPIO_PIN_A0
#define GPIO_PIN_USB_DETECT 9
#define GPIO_PIN_SDCARD_OFF 8

#define LCD_SET_COMMAND_MODE() USEX(GPIO_ODATA) &= ~(1 << LCD_GPIO_PIN_A0);
#define LCD_SET_DATA_MODE() USEX(GPIO_ODATA) |= (1 << LCD_GPIO_PIN_A0);

#define IO_END_FRAME() USEX(GPIO_ODATA) |= (1 << LCD_GPIO_PIN_CS) | (1 << EE_GPIO_PIN_CS) | (1 << SD_GPIO_PIN_CS);
#define LCD_START_FRAME() {IO_END_FRAME(); USEX(GPIO_ODATA) &= ~(1 << LCD_GPIO_PIN_CS);}
#define SD_START_FRAME() {IO_END_FRAME(); USEX(GPIO_ODATA) &= ~(1 << SD_GPIO_PIN_CS);}
#define EE_START_FRAME() {IO_END_FRAME(); USEX(GPIO_ODATA) &= ~(1 << EE_GPIO_PIN_CS);}
#define SPIRAM_START_FRAME() {IO_END_FRAME(); USEX(GPIO_ODATA) &= ~((1 << EE_GPIO_PIN_CS) | (1 << LCD_GPIO_PIN_CS));}
#define LCD_END_FRAME IO_END_FRAME
#define SD_END_FRAME IO_END_FRAME
#define EE_END_FRAME IO_END_FRAME
#define SPIRAM_END_FRAME IO_END_FRAME

#endif
